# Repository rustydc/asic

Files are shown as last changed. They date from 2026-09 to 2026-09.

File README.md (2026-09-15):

# ASIC LLM research prototype

This repository contains the software-model starting point for a fixed-weight
LLM inference appliance built around the Qwen3.5 dense hybrid geometry.

* [`ARCHITECTURE.md`](ARCHITECTURE.md) records the current appliance and pipeline
  decisions, including the balanced FULL-retrieval policy for every global layer.
* [`fixed_llm_poc.py`](fixed_llm_poc.py) is the correctness-oriented PyTorch
  reference model. Its parameter names match the Hugging Face `Qwen3_5` text
  model so released checkpoints load with a prefix rename. It is not an
  optimized long-context training kernel.
* [`fabric/`](fabric/) defines the fixed-weight fabric tile: a via-programmed
  coefficient ROM feeding 64 MAC columns. It holds the bit-exact reference
  model, the coefficient compiler and via-pattern export, the model-to-tile
  mapping with area and latency estimates, synthesizable RTL verified
  against the model with Icarus Verilog, a yosys flow that measures the
  column datapath on open liberty files (sky130, IHP SG13G2, NanGate 45,
  ASAP7), an OpenSTA driver for pre-layout timing, and an OpenROAD
  place-and-route driver with its sky130 and ASAP7 results.
* [`clash/`](clash/) contains a synthesizable four-stage ASIC-shard seed with a
  deliberately small fixed-coefficient datapath for early RTL and P&R work.
* [`sim/`](sim/) contains the cycle-stepped 32-stage appliance simulator for
  scheduling, phased global execution, backpressure, link, memory-bandwidth,
  and retrieval-geometry sweep experiments, with an energy model that turns
  the measured energy per MAC into board power at the simulated throughput.
* [`training/`](training/) contains the Qwen3.5 checkpoint importer, the
  retrieval candidates, and a layer-wise activation-distillation harness.
* [`hw/`](hw/) contains the block-level board description of the host-attached
  1U (eight layer ASICs, two head-mode ASICs, sixteen LPDDR5X devices, one
  FPGA on a PCIe cable, a BMC, redundant CRPS supplies), its consistency
  checks including a throughput-driven power budget, the rendered block
  diagram, a derivation of the ASIC package and ball map from the power
  model and the interface list, and a generator that turns the description
  into a KiCad 7 project with the board outline and chassis keep-outs,
  placement, stackup, all nets, and the activation ring routed.

## Reference geometries

| Preset | Source model | Hidden | Layers | Body params | Per-ASIC shard |
| --- | --- | ---: | ---: | ---: | ---: |
| `qwen3_5_9b` (default) | Qwen3.5-9B-Base | 4096 | 8 × (3 R + 1 G) | 6.9B | 866M |
| `qwen3_5_4b` | Qwen3.5-4B-Base | 2560 | 8 × (3 R + 1 G) | 3.6B | 447M |

Both presets share the same recurrent heads (32 value × 16 key, 128-dim),
attention heads (16 query × 4 KV, 256-dim), and therefore the same per-context
state formats. Only the fabric width differs, so the 4B is a narrow build of the
same design. Select a preset with `ASICLMConfig.from_preset(name)`; every
variant in `training/variants.json` names one.

## Run

Run the tiny model smoke test and the geometry report in an environment with
PyTorch installed:

```bash
python fixed_llm_poc.py
python -m unittest discover -s training/tests -t .
python -m unittest discover -s sim/tests -t .
python -m unittest discover -s fabric/tests -t .   # RTL tests need iverilog
python -m unittest discover -s hw/tests -t .
```

Import a released checkpoint (needs the `safetensors` package):

```bash
python -m training.qwen35_import --checkpoint /models/Qwen3.5-9B-Base \
    --output checkpoints/asic_init.pt
```

Simulate both geometries:

```bash
python -m sim.run --config sim/config/baseline.json     # 9B
python -m sim.run --config sim/config/qwen35_4b.json    # 4B
python -m sim.run --config sim/config/qwen35_9b_7nm_hbm.json   # 9B, 7 nm-class die, HBM
python -m sim.run --config sim/config/qwen35_9b_3nm_hbm.json   # 9B, 3 nm-class die, HBM
```

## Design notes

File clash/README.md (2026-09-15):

# Clash RTL seed

This directory contains a synthesizable **structural seed**, not the complete 8B
model implementation. It makes the first hardware boundary concrete:

* a tagged activation packet containing no persistent context state;
* four registered, independently operating stages in `R/R/R/G` order;
* literal fixed coefficients that synthesize as constants/connectivity rather
  than an addressed model-weight memory;
* saturating accumulator-to-activation requantization;
* a top entity suitable for Verilog or VHDL generation.

The demo activation width is 16 elements. Expanding it directly to 4096 and
copying the placeholder matrix is not the intended implementation: literal
coefficients do not scale past a demo. The fabric tile that replaces the stage
shell is specified in `fabric/` with synthesizable SystemVerilog in
`fabric/rtl/` and a bit-exact Python model. The next step is to instantiate
that tile array behind these stage boundaries.

## Generate RTL

With GHC, Cabal, and Clash 1.8 installed:

```bash
cd clash
cabal update
cabal build all
cabal test
cabal exec clash -- --verilog src/FixedLLM.hs -main-is FixedLLM.topEntity
```

Generated HDL appears below `verilog/FixedLLM.topEntity/`. The exact location
may include Clash version-specific naming.

## Deliberate omissions

The current global stage is the same registered fixed-projection shell as the
recurrent stages. It does not yet implement recurrent state RAM, local-window
storage, compressed block construction, top-K FULL retrieval, dynamic Q/K/V
attention, backpressure, or the external-memory interface. Those blocks should
be introduced behind the stable `WorkItem` and stage boundaries, with every
global stage retaining the same FULL-retrieval service contract.

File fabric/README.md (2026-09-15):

# Fixed-weight fabric tile

The fabric is the part of the die that holds the model. This directory defines
its unit, the **tile**: a via-programmed coefficient ROM feeding a row of
multiply-accumulate columns. The reference model, the coefficient compiler,
the synthesizable RTL, and the model-to-fabric mapping all live here, and the
RTL is checked bit-exact against the model with Icarus Verilog.

```bash
python -m fabric.tile                        # tile budget for the 9B geometry
python -m fabric.tile --geometry qwen3_5_4b  # and the 4B
python -m unittest discover -s fabric/tests -t .   # model, mapping, and RTL tests
```

## Why a ROM and not pure wiring

A coefficient that is literally a wire between an input line and an
accumulator can never be time-multiplexed, because a static wire cannot select
a different multiple on a different cycle. Pure wiring therefore means one
adder leaf per coefficient, all 866 million of them used once per token. That
is not buildable. The only way a mask-programmed coefficient can share
arithmetic is for the mask to encode a *bit* that a wordline reads out, which
is a ROM.

So the tile is a mask ROM with a very wide read port and the arithmetic sitting
against its bitlines. The architecture doc's "no addressed weight store" is
kept in the sense that matters: the coefficient never leaves the tile, the
read is a few tens of micrometres of bitline, and there is no weight bus,
cache, or DRAM traffic. What is given up is the idea that the weights are
wiring. They are a via pattern in a ROM array, which is denser anyway.

## Tile microarchitecture

```text
                 activations x[r], x[r+1]   (P = 2 rows per cycle, int8)
                        |
          +-------------v--------------+
          | shared multiples per bank  |   0, x, 2x, 3x, 4x, 5x, 6x, 7x
          | (shifts + three adders)    |   11-bit signed
          +----+----+----+---- ... ----+
               |    |    |               one 8-way bus per bank
   ROM row r   v    v    v
   +----+   +--------------------------------------------------+
   |via |-->| column c: select multiple by |w[r][c]|, add/sub  |--> acc[c]  (24-bit)
   |ROM |   | column c+1 ...                                   |
   |    |   +--------------------------------------------------+
   4096 rows x 64 columns x 4 bits = 1 Mbit, 2 banks (even / odd rows)
```

| Parameter | Value | Note |
| --- | ---: | --- |
| Rows (input dims per tile) | 4096 (9B), 2560 (4B) | equals the hidden width; one pass covers a full input vector |
| Columns (outputs per tile) | 64 | |
| Coefficient format | symmetric int4, −7..7 | never −8, so the magnitude selects one of 8 multiples |
| Activation format | int8 | |
| Rows per cycle | 2 | two ROM banks read in parallel; the main area-versus-latency knob |
| Accumulator | 24-bit | worst case 4096 × 127 × 7 fits with margin |
| Requantization | `sat8((acc × mult + 2^(shift−1)) >> shift)` | per-column 16-bit multiplier and 5-bit shift from SRAM, not from the fabric |
| Pass length | rows / rows-per-cycle = 2048 cycles | |

A pass starts by loading the accumulators with chained partial sums (zero for a
fresh pass), consumes two activations per cycle in row order, and after 2048
cycles the shared requantizer walks the columns and publishes the resolved
accumulators and the requantized int8 outputs together. Matrices
wider than 64 outputs use more tiles side by side. Matrices deeper than the
tile, such as the 12288-wide FFN down-projection, use three tiles over
disjoint row ranges in parallel and a partial-sum reduction after them, so
every pass takes the same 2048 cycles.

The per-column requantization constants are the only per-model numbers that
are not in the via pattern. They live in SRAM loaded at boot over the
management SPI, about 80 KB per die.

## Personalization

Every coefficient bit is the presence or absence of one via in the ROM array.
Ten chips, ten via masks, one base mask set. The base wafers can be processed
up to the via layer and banked, then personalized. `Tile.via_count` and
`via_coordinates` produce the pattern the GDS writer places; the row and bit
addressing is fixed here, the bit-cell geometry comes from the foundry ROM
compiler.

Verification per variant is: DRC on the via layer, `decompile` of the via maps
against the quantized weights, and `tile_forward` against `reference_matmul`
on random vectors. No timing closure per variant, because the ROM read and
the column datapath do not depend on which vias are present.

## Mapping the models

The mapping counts tiles per matrix for one `R,R,R,G` shard and for a head
die holding half the vocabulary. All numbers use the placeholder density model
below.

| | 9B layer die | 9B head die | 4B layer die | 4B head die |
| --- | ---: | ---: | ---: | ---: |
| Tiles | 3306 | 1940 | 2858 | 1940 |
| Coefficients | 866M | 509M | 447M | 318M |
| Utilization | 99.9% | 100% | 97.7% | 100% |
| Area at 2 rows/cycle | 242 mm² | 142 mm² | 176 mm² | 119 mm² |
| Latency per layer, 800 MHz | 10.2 µs | 2.6 µs (die) | 6.4 µs | 1.6 µs (die) |
| Fabric energy per token | 62 µJ | 37 µJ | 32 µJ | 19 µJ |

The head slice fits inside a layer die's tile count in both geometries, which
is what makes the head-mode personalization possible. At 50K tokens/s the
fabric energy is about 3 W per 9B layer die before clocks, memory, and I/O.

The rows-per-cycle knob trades column area for latency. ROM area is fixed by
the coefficient count; the MAC columns scale with rows per cycle.

| Rows/cycle | Clock | 9B layer die area | ROM / MAC | Latency per layer | Pass |
| ---: | ---: | ---: | ---: | ---: | ---: |
| 1 | 800 MHz | 218 mm² | 104 / 106 mm² | 20.5 µs | 5.1 µs |
| 2 | 800 MHz | 242 mm² | 104 / 130 mm² | 10.2 µs | 2.6 µs |
| 4 | 800 MHz | 291 mm² | 104 / 179 mm² | 5.1 µs | 1.3 µs |
| 2 | 500 MHz | 242 mm² | 104 / 130 mm² | 16.4 µs | 4.1 µs |

Two rows per cycle is the baseline. The simulator's stage times are derived
from it: 102 ticks (10.2 µs) per 9B layer, 26 ticks per head die.

Because a layer is four sequential passes, a layer stage could accept a new
token every pass (2.6 µs) while a token takes four passes to get through. The
simulator currently treats a layer as one stage with initiation interval equal
to latency, so it understates fabric throughput by up to 4×. It does not
matter yet because the global stage's memory traffic is the bottleneck at
about 66 µs.

## Density model

`DensityModel` holds the numbers behind the tables. The MAC-column entries
are calibrated from open-tooling synthesis (next section); the rest are
placeholders the MPW tile is meant to replace.

| Entry | Value | Source |
| --- | ---: | --- |
| ROM area | 0.03 µm² per bit | placeholder: via-ROM compiler cell at the target node |
| MAC column | 115 µm² per bank | 380 NAND2 equivalents from 64-column sky130 synthesis, at a 0.30 µm² 28 nm NAND2 |
| Accumulator, requantizer share, registers | 385 µm² per column | 1280 NAND2 equivalents, same source |
| Tile overhead | 2500 µm² | placeholder: multiples generator, ROM periphery, control |
| Clock | 800 MHz | placeholder: ROM read plus column add in one cycle |
| ROM read | 3 fJ per bit | placeholder |
| MAC | 60 fJ per coefficient | placeholder |

At these numbers a 28 nm-class 9B layer die is 242 mm², about 43 percent
ROM and 54 percent MAC columns. The timing-clean column (next sections)
costs about 45 percent more than the first ripple-carry version; that is the
price of a pipeline with no carry chain per cycle. At a 16 nm-class node expect roughly
half. If the ROM cell comes in denser than 0.03 µm² per bit, the MAC columns
dominate and one row per cycle becomes the better trade.

## Open tooling and open PDKs

Yes, the column datapath synthesizes with open tooling today, and the numbers
above already come from it. `fabric/synth.py` runs yosys (native or the
`yowasp-yosys` PyPI build) on `fabric_columns` against any liberty file:

```bash
pip install yowasp-yosys
curl -LO https://raw.githubusercontent.com/The-OpenROAD-Project/OpenROAD-flow-scripts/master/flow/platforms/sky130hd/lib/sky130_fd_sc_hd__tt_025C_1v80.lib
python -m fabric.synth --liberty sky130_fd_sc_hd__tt_025C_1v80.lib --rows 256 --cols 16 --rows-per-cycle 2
FABRIC_LIBERTY=$PWD/sky130_fd_sc_hd__tt_025C_1v80.lib python -m unittest fabric.tests.test_synth
```

Measured first on the original ripple-carry column (16 columns, 256 rows,
two rows per cycle) on two manufacturable 130 nm libraries and two predictive
advanced-node kits:

| Library | Kind | NAND2 | Cells | Per column | NAND2-eq per column |
| --- | --- | ---: | ---: | ---: | ---: |
| SkyWater sky130 HD (130 nm) | manufacturable | 3.75 µm² | 12,087 | 5221 µm² | 1392 |
| IHP SG13G2 (130 nm) | manufacturable | 7.26 µm² | 12,027 | 9349 µm² | 1288 |
| NanGate 45 (FreePDK45) | predictive | 0.80 µm² | 12,999 | 1043 µm² | 1307 |
| ASAP7 (7 nm FinFET) | predictive | 0.058 µm² | 11,974 | 74 µm² | 1271 |

Four libraries spanning 130 nm to 7 nm agree within ten percent once
normalized to their own NAND2, so NAND2 equivalents are the number to carry.
The first synthesis run also caught a design error: a per-column requantizer
multiplier that tripled the column area, now a single unit shared across the
64 columns.

The timing work below reshaped the column (carry-save accumulate,
signed-digit taps, a deeper shared requantizer). A full 64-column tile on
sky130 now costs 1663, 2050 and 2808 NAND2 equivalents per column at 1, 2 and
4 rows per cycle, which is the 1280 + 380 per bank the density model uses.

ASAP7 ships its cells in several liberty files; merge them first:

```bash
python -m fabric.synth --merge asap7_tt.lib --liberty SIMPLE.lib --liberty INVBUF.lib \
    --liberty AO.lib --liberty OA.lib --liberty SEQ.lib
python -m fabric.synth --liberty asap7_tt.lib --rows 256 --cols 16 --rows-per-cycle 2
```

On the predictive kits: FreePDK15 (NC State, 15 nm FinFET) is the same kind
of thing as ASAP7 and NanGate 45, an academic model of a node with no fab
behind it. Its standard cells are the NanGate 15 nm library distributed by
Silvaco behind a registration, so it is not fetchable in a script the way the
OpenROAD platforms are, and ASAP7 already gives the below-28 nm bracket. Any
of them is fine for relative area, useless for a tapeout.

What open PDKs can and cannot do for this project:

* **Relative column cost: yes, done above.** Predictive kits (NanGate 45,
  ASAP7, FreePDK15) bracket the target node from both sides.
* **The MPW tile: yes.** A 1024 × 64 test tile on sky130 or IHP SG13G2 is
  about a square millimetre of columns plus a hand-drawn via-ROM array, and
  both processes run open shuttles. That measures the column datapath, the
  ROM cell, and the personalization flow end to end, at 130 nm.
* **Timing: yes, pre-layout and placed-and-routed.** OpenSTA builds from
  source in a few minutes and times the yosys netlist against the same
  liberty files; OpenROAD then places, buffers, clocks and routes it on
  the sky130 and ASAP7 platform files. See the next two sections.
* **The production die: no.** At 130 nm the ROM cell is 30 to 50 times larger
  than at 28 nm, so the 9B layer die would be several thousand square
  millimetres. The production node needs a foundry PDK under NDA.
* **OpenRPDK28 (RIOS Lab): not yet.** It is an academic 28 nm template
  under construction with device models and rule decks but, as far as its
  repository shows, no standard-cell library or liberty timing, and it is
  not tied to a foundry, so nothing built on it can be fabricated. It may
  become useful for checking a via-ROM cell against 28 nm-class design rules
  once it matures.

A further density lever, not in the baseline, is current-mode readout: drive
wordlines with the activation as a pulse width, sum bitline currents, and
digitize once per column. That removes the column datapath entirely and is
the only path well below 0.15 µm² per coefficient, at the cost of analog
precision risk. It is a second-generation experiment.

## Timing on 130 nm and 7 nm

`fabric/sta.py` runs OpenSTA on a netlist written by `fabric/synth.py`
(`--target-ps` for timing-driven mapping, `--netlist` to keep it), with a
clock constraint and ten percent input and output delays:

```bash
python -m fabric.synth --liberty sky130.lib --rows 256 --cols 16 --rows-per-cycle 2 \
    --target-ps 2500 --netlist net_sky130.v
python -m fabric.sta --sta /path/to/OpenSTA/build/sta --liberty sky130.lib \
    --netlist net_sky130.v --period-ps 2500 --report
```

Results for the column datapath at two rows per cycle, typical corner:

| Library | Critical path | Of which unbuffered fanout | Logic-depth limit |
| --- | ---: | ---: | ---: |
| sky130 HD, 130 nm | 4.25 ns | 1.4 ns (80-load flop) | 235 MHz, ~310 MHz buffered |
| ASAP7, 7 nm predictive | 0.73 ns | 0.14 ns (52-load flop) | 1.37 GHz, ~1.7 GHz buffered |

What these numbers are: post-synthesis, pre-layout, no wire load, no clock
tree, ideal clock, one corner, and no cell sizing or buffering beyond what
ABC does inside one combinational block. Flop-driven nets are not buffered,
so the first line of every critical path is a fat unbuffered fanout that
place-and-route would fix; the "buffered" column subtracts it and charges a
buffer tree instead. ASAP7 maps to its smallest cells throughout, so it is
pessimistic in the other direction. Budget 20 to 40 percent on top for wires.

Read across the nodes: 130 nm at roughly 300 MHz and predictive 7 nm at
roughly 1.7 GHz bracket a 28 nm-class part somewhere around 0.6 to 1.2 GHz
for this logic depth. The 800 MHz placeholder is inside that range, not
proven by it. The MPW tile and a foundry library settle it.

Getting here changed the design, and every change was driven by a reported
critical path:

1. **Requantizer multiplier per column** (3000 cells per column): made one
   shared unit that walks the columns after the pass.
2. **41-bit ripple-carry adds** in the requantizer at 6 to 9 ns on sky130:
   yosys emits ripple adders and ABC cannot restructure carry chains, so the
   multiply became a carry-save tree with the rounding constant folded in and
   the final add runs in three 14-bit chunks over three stages.
3. **Column select fanout** (`q_col` on 600 accumulator mux bits): replaced by
   a one-hot walking select, 69 loads per bit regardless of column count.
4. **Control strobes** merged back into one 600-load net by synthesis even
   with `keep`: the per-column copies are now their own module with
   `keep_hierarchy`.
5. **Pre-adders for 3x, 5x, 7x** on the activation path: every coefficient
   magnitude is now a signed pair of power-of-two taps, so stage A has no
   arithmetic at all.
6. **24-bit accumulate and the term sum**, ripple again: both are carry-save.
   The accumulator is a (sum, carry) pair with a constant-depth 3:2 reduction
   per cycle; the carries resolve once per pass in the requantizer walk, in
   two 12-bit chunks. The term sum reduces the four taps and the negation
   count to a carry-save pair at accumulator width, so no width change and
   no wrap can occur.
7. **Datapath resets** removed; `start` loads the accumulators, everything
   else free-runs, and only control keeps an asynchronous reset.

The column pipeline is now A (inputs), B (term reduction), C (accumulate);
the requantizer is select, two resolve stages, multiply, three add stages,
and shift/saturate, nine cycles of latency after the 64-cycle walk. All of
it stays bit-exact against the Python model, which never changed.

## Place and route

`fabric/pnr.py` drives OpenROAD through floorplan, timing-driven global
placement, resize and buffering, clock-tree synthesis, hold repair, global
routing, and post-route timing on wire parasitics extracted from the global
route. It uses the platform files from OpenROAD-flow-scripts (LEF, RC
tables, track scripts) and the same netlists OpenSTA timed above:

```bash
micromamba create -p eda -c litex-hub -c conda-forge openroad   # or build from source
git clone --depth 1 https://github.com/The-OpenROAD-Project/OpenROAD-flow-scripts orfs
python -m fabric.pnr --openroad eda/bin/openroad --platform sky130hd \
    --platforms-dir orfs/flow/platforms --netlist net_sky130.v \
    --period-ps 3000 --utilization 35 --work pnr_sky130
python -m fabric.pnr --openroad eda/bin/openroad --platform asap7 \
    --platforms-dir orfs/flow/platforms --netlist net_asap7.v \
    --liberty asap7_tt.lib --period-ps 700 --utilization 45 --work pnr_asap7
```

Results for the same 256-row, 16-column, two-rows-per-cycle slice, after
global routing, typical corner (`fabric/results/pnr_*.json` holds the parsed
numbers and the final critical path):

| | sky130 HD, 130 nm | ASAP7, 7 nm predictive |
| --- | ---: | ---: |
| Target period | 3.00 ns | 700 ps |
| Worst slack | −1.15 ns | −2.7 ps |
| Achievable clock | **241 MHz** | **1.42 GHz** |
| Pre-layout estimate | 235 MHz (310 buffered) | 1.37 GHz (1.7 buffered) |
| Clock insertion / skew | 1.9 ns, 8 levels / 470 ps | 280 ps, 4 levels / 73 ps |
| Hold buffers | 3051 | 1584 |
| Design area | 215,071 µm² (47 %) | 2,623 µm² (45 %) |
| Placed area before repair | 159,971 µm² | 2,646 µm² |
| Instances | 28,034 | 23,621 |
| Wirelength | 1.48 m | 131 mm |
| Routing overflow (global) | 297 edges, ≤ 6 per edge | 0 |

The pre-layout numbers hold up. On ASAP7 the routed design is a little
faster than the unbuffered estimate: the resizer fixes the fanout the STA
run flagged, and wires, the clock tree and 73 ps of skew cost less than
that fix gains. On sky130 the routed flop-to-flop path is 4.2 ns, the same
as the unbuffered pre-layout path, so none of the expected buffering gain
arrived (see below); the 2345-sink clock tree built from `clkbuf_4` alone
is eight levels and 1.9 ns deep, but its 470 ps of skew happens to favour
the worst path. The 28 nm-class bracket stays where the previous section
put it, roughly 0.6 to 1.2 GHz, with the 800 MHz placeholder inside it.

What limits each node now:

* **ASAP7:** the critical path is twenty-seven XOR and NAND levels in the
  requantizer, the ripple form ABC leaves a 14-bit chunk add in, plus the
  skew between two clock branches. Both are design choices: narrower
  chunks or a conditional-sum adder should be worth 100 to 150 ps, and a
  two-level clock mesh removes most of the skew. Neither is worth doing
  before the target library is known.
* **sky130:** the critical path runs through the walking select and the
  requantizer input mux, and one `o41ai_4` cell on it drives a 64 fF net
  at a 0.9 ns slew that the resizer gave up on (`RSZ-0062`, three times).
  That one cell is 0.85 ns of a 4.2 ns path. It is a buffering failure
  rather than a logic-depth limit; a hand-placed buffer tree on the select
  would recover most of the missing 300 MHz. It only matters for the MPW
  tile.

Area moves in the expected direction. Sky130 grows 34 percent in place and
route, almost all of it the 3051 hold buffers that propagated-clock skew
forces on a design whose datapath registers have no logic between them in
the walk, plus the clock tree. ASAP7 does not grow at all because the
resizer downsizes 10,390 cells that yosys had mapped larger than needed,
which pays for its 1584 hold buffers. Per column slice the routed area is
3585 NAND2 equivalents on sky130 and 2827 on ASAP7, against 2050 for a
column of the 64-wide tile pre-layout; the 16-column slice amortizes the
shared requantizer over four times fewer columns, which accounts for most
of the difference. The density model still carries the pre-layout
64-column figure. The sky130 run says place and route can add a third on
top of it, mostly hold buffers a better clock tree would reduce, and the
ASAP7 run says it can add nothing; the die-size table should be read with
that spread in mind until the target library settles it.

What this run is not: detailed routing (`--detailed-route` runs it, at
several times the wall time), a signoff extraction, multiple corners, or a
power grid. The global router reports no overflow on ASAP7 and a few
hundred lightly overfull edges on sky130 at 35 percent target utilization,
so both would detail-route; the sky130 slice is pin-limited, with 1390
ports on a 0.68 mm square, which is an artifact of routing a slice rather
than the whole tile.

Two things the flow had to work around in the litex-hub OpenROAD build of
February 2024: `report_wire_length` crashes on a typo in its error path,
so wirelength comes from the router's own log line, and `> file`
redirection on several report commands writes empty files, so every report
goes to the log and `parse_results` reads that.

## Detailed routing, power grid and IR drop

`--detailed-route` extends the flow: well taps and the platform's power
grid go in at floorplan (`pdngen` with the OpenROAD-flow-scripts strategy,
M1/M2 rails with M5/M6 stripes on ASAP7, met1 rails with met4/met5 stripes
on sky130), and after global routing it runs TritonRoute, fill cells,
OpenRCX extraction, timing on the extracted parasitics, `report_power`,
and static IR-drop analysis of both supply nets.

```bash
python -m fabric.pnr --openroad eda/bin/openroad --platform asap7 \
    --platforms-dir orfs/flow/platforms --netlist net_asap7.v \
    --liberty asap7_tt.lib --period-ps 700 --utilization 25 \
    --detailed-route --work pnr_asap7_drt --json
```

ASAP7, same 256-row 16-column slice, after detailed routing and
extraction (`fabric/results/pnr_asap7_signoff.json`):

| | ASAP7, 7 nm predictive |
| --- | ---: |
| Detailed-route DRC violations | 0 (8 iterations); 0 antenna violations |
| Timing on extracted parasitics | 700 ps met exactly, **1.43 GHz** |
| Same path on global-route estimates | −8 ps |
| Clock skew | 75 ps |
| Cells (before 38,086 fillers) | 26,433 |
| Design area | 3,311 µm² at 31 % of a 107 µm die |
| Wirelength | 157 mm |
| Power (default 10 % activity, 1.43 GHz) | 17.9 mW: 61 % internal, 39 % switching |
| Static IR drop, VDD | 364 mV worst at the core edge, 12 mV average |

The timing story does not change from global routing to signoff: the
extracted parasitics come in slightly under the global-route estimate, and
the slice closes at exactly the 700 ps it was asked for. The pre-layout
bracket for 28 nm stands.

The power grid is the new information. The slice draws 1.7 W/mm² at the
default activity, which is high, and the platform's default grid was not
made for that: 18 nm M1/M2 rails fed from M5/M6 stripes every 5.4 µm lose
100 mV or more on half of the cells, and 364 mV at the right core edge,
where the last stripe sits 3 µm from the boundary. That result is with a
supply point on every top-layer node (this build turns `-dx 20 -dy 20`
into 4.2 million sources), so it is the distribution loss alone; a real
bump grid adds to it. For the tile this says two things: stripe pitch and
rail width are first-order design parameters at this power density, and
the density model's 800 MHz at 28 nm will need a grid sized from the
measured current, not the platform default. It does not change the area
model.

Getting a pin-dense slice through this build's TritonRoute took some
care, and each item is a flag or an experiment in `fabric/pnr.py`:

* constants must be tie cells (`hilomap` on the mapped netlist, with
  `opt_clean -purge` and `setundef -zero` first) or the router refuses
  the supply-typed nets they become;
* buffers inserted by post-route timing repair must be legalized and the
  design re-routed before detailed routing;
* on ASAP7 the router could not reach a handful of M4/M5 I/O pins on the
  left and bottom edges whatever the stub length or spacing (experiments
  A and B); with 1 µm stubs on the top and right edges only (experiment
  C) it routes cleanly;
* `pin_access` before global routing puts guides on M9 on ASAP7 and is
  therefore off there;
* the routing derating follows the flow scripts (0.25 on ASAP7, 0.2 on
  sky130): at 0.5 the slice overflowed by a few edges and the guides of
  those nets were unusable;
* on sky130 the router rejected every net on a pin whose li1 and met1
  shapes are separate LEF `PORT`s (xor2 B, dfrtp RESET_B, mux, fa) when
  the ports straddle a gcell boundary; the driver merges those ports in
  a copy of the cell LEF, and the resizer is told not to use the probe
  cells it had been picking as hold buffers.

sky130 signoff: pending (see the results file when it lands).

## RTL

`rtl/fabric_tile.sv` is the synthesizable tile with the ROM as a constant
array loaded from a hex image. It is parameterized in rows, columns,
coefficient and activation width, rows per cycle, and accumulator and
requantizer widths. In silicon the ROM array and the multiple-select crossbar
become a hard macro; the RTL is the functional stand-in and the synthesis
baseline for the column datapath.

`rtl/tb_fabric_tile.sv` reads vectors written by `fabric.tile.emit_vectors`,
streams the activations with occasional bubbles, and compares the raw
accumulators and requantized outputs against the model. The tests run three
configurations through Icarus Verilog: 64×8 with chained partial sums, 256×64
at four rows per cycle, and 4096×16 at full depth.

## What is next

1. Detailed routing and a multi-corner pass of the OpenROAD flow above, a
   buffer tree on the walking select for sky130, and then the same flow on
   the target library.
2. A via-ROM compiler cell from the foundry, or a hand-drawn cell for the MPW,
   to replace the ROM area and read energy placeholders.
3. The GDS writer: `via_coordinates` into the ROM macro's bit-cell grid.
4. Pass-level pipelining in the simulator so a layer stage's initiation
   interval is one pass rather than four.
5. A multi-token variant of the column datapath for chunked prefill, which
   amortizes the ROM read across a chunk of tokens from one context.

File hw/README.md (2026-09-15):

# Appliance board (revision A0)

Block-level schematic capture for the first appliance board. `board.yaml` is
the source of truth; `python -m hw.board` checks it and regenerates
`board.svg` (block diagram) and `board.md` (bill of materials, power, pin
budget, ring order). Everything here is a budget to validate, not a vendor-
confirmed number, until the ASIC pinout and power are characterized.

```bash
python -m hw.board            # check, then write board.svg and board.md
python -m unittest discover -s hw/tests -t .
```

## Form factor: a host-attached 1U

The board is a single 420 × 360 mm board in a 1U rack chassis, attached to
a host over a PCIe cable. The first draft was a full-length PCIe card; the
energy model below moved it out of the slot. At 3 pJ per MAC the board
draws 0.5 to 1.6 kW of input across the throughput range, which is a rack
power supply and a row of fans, not a 600 W auxiliary connector on a
passively cooled card. The 1U also has the room the 50K tokens/s package
needs (29 mm bodies, 62 mm column pitch, 76 mm row-change hop) and a
management controller. The chassis layout:

* rear panel: the SlimSAS 8i host connector next to the FPGA, the BMC's
  RJ45, the optional SFP+ cage, the status LEDs;
* rear right: the PSU bay with two CRPS modules in a 1+1 redundant pair;
* the ring runs front to back down the middle of the board, FPGA and head
  ASICs at the rear, the row change under the front fans;
* front: six 40 mm fans blowing front to back over the two ASIC rows.

The KiCad generator keeps the card as a second form factor
(`form_factor_key: pcie_card`), which still builds at the 14.5K rating with
the 23 mm package; the tests check both.

## Population

| Part | Qty | Role |
| --- | ---: | --- |
| Layer ASIC | 8 | four decoder layers each, personalized coefficient masks, layer-mode strap |
| Head ASIC | 2 | same die, head-mode strap, each holds half of the 248K-row LM head; no memory |
| LPDDR5X 16 Gb x32 | 16 | two per layer ASIC: 4 GB and 77 GB/s raw per ASIC at 9600 MT/s |
| Controller FPGA | 1 | PCIe Gen4 x8 endpoint over the host cable, ring source and sink, sampling, scheduling |
| DDR4 x16 | 4 | 4 GB on the FPGA for the embedding table and per-context metadata |
| Clock generator | 1 | reference clock to all eleven devices |
| BMC | 1 | AST2600-class: PSU PMBus, fan control, thermal, FPGA console, its own Ethernet |
| Host cable connector | 1 | SlimSAS 8i (SFF-8654): PCIe Gen4 x8 plus sideband to a host adapter card |
| CRPS receptacle | 2 | 12 V from each supply module, 1+1 redundant |
| Fan header | 6 | 4-pin PWM, one per front fan |
| SFP+ cage | 1 (optional) | standalone 10GbE operation, rear panel |

## Topology

One unidirectional activation ring:

```text
FPGA -> A0 -> A1 -> A2 -> A3 -> A4 -> A5 -> A6 -> A7 -> H0 -> H1 -> FPGA
```

Each hop is the 32-bit source-synchronous DDR link from the architecture doc
(36 signals, 2 GB/s raw, under 80 mm). Head chips forward the incoming hidden
vector unchanged and append their top-k logits and partial softmax sum, so no
broadcast path is needed. The FPGA merges the two lists and samples.

Layer ASICs sit in two rows of four so the ring snakes out along row A and
back along row B, ending next to the FPGA. Both head chips sit at the rear
end of row B, the FPGA directly beside H1. Each layer ASIC has one LPDDR5X
device on either side.

Management is a SPI bus from the FPGA with one chip select per ASIC, a JTAG
chain through all eleven devices, and a fanned-out reference clock. Each ASIC
has a two-pin mode strap (layer or head). The BMC owns the chassis: PSU
PMBus, fan PWM and tach, the core regulators' PMBus, the FPGA's UART
console, and its own Ethernet port.

## Power

ASIC power is no longer a placeholder: it is throughput times energy per
token, from the `power_model` block in `board.yaml`. The one measured input
is the energy of a fixed-weight multiply-accumulate in the column datapath,
0.39 pJ on ASAP7 at the tool's default activity
(`fabric/results/pnr_asap7_signoff.json`), which derates to about 1 pJ for
real activity and projects to 2 to 4 pJ on a 28 nm-class node; the model
carries 3 pJ. Each layer ASIC does 866M MACs per token (9B geometry), each
head ASIC 508M, and the layer ASICs also move about 4.2 MB per token of
index and KV traffic at roughly 40 pJ per byte. The other parts keep fixed
budgets (1 W per LPDDR5X, 25 W FPGA, 5 W BMC, 12 W per fan).

At the simulator's 14.5K tokens/s ceiling that is 43 W per layer ASIC and
517 W of load, 608 W of 12 V input at 85 percent regulator efficiency.
`board.md` tabulates the same at 5K, 25K and 50K tokens/s: the board runs
from about 330 W to 1.66 kW of input across the throughput range, and a
layer ASIC's core rail goes from 21 A to 177 A at 0.8 V. The supply is
therefore two 2000 W CRPS modules in a 1+1 redundant pair, one of which
carries the whole load, and each ASIC needs a multiphase core regulator.
A 7 nm-class die at about 1 pJ per MAC would put the whole range back under
600 W and make the card viable again; the process choice is the biggest
lever on the power supply and the enclosure.

The power tree is a 12 V intermediate bus from the CRPS modules into
point-of-load regulators. Each ASIC gets its own core buck with PMBus
telemetry so per-chip current is observable during bring-up. The LPDDR5X
rails, 1.8 V I/O, FPGA rails, DDR4 rails, and 3.3 V housekeeping are shared.

## Host interface: PCIe over a cable, and why not Ethernet or PoE

**PoE is out.** The highest PoE class (802.3bt Type 4) delivers 71 W to the
device. This board needs hundreds of watts at any useful throughput. Even a
4B-geometry build at the lowest rate in the table sits well above the PoE
ceiling once the FPGA and memory are counted.

**Ethernet as the data path is viable but not the first build.** The token
traffic is tiny. At 50K tokens/s with a few hundred bytes per token, both
directions together are under 20 MB/s, and a 128K prefill moves 512 KB of
token ids. Even 1GbE would carry it. The reasons to still start with PCIe:

* the FPGA's hard PCIe block is the cheapest working host link, with no
  network stack to write in fabric;
* PCIe round trips are a few microseconds, below the 250 to 500 µs token
  latency target, while a network hop adds tens of microseconds and jitter.

The 1U is host-attached: a SlimSAS 8i cable from the rear panel to a
retimer or host adapter card in the server next to it, the same arrangement
as an external PCIe expansion chassis. PCIe Gen4 x4 is enough bandwidth; the
board wires x8 because the FPGA's hard block is x8 and the cable carries it.

The SFP+ cage on the rear panel keeps the standalone-appliance option open.
The FPGA transceivers are there anyway, so a later firmware can serve a UDP
or gRPC-style token protocol over 10GbE with no board change, and the
chassis already has its own supply and management.

## ASIC package and ball map

`python -m hw.pinout` derives the ASIC package and its ball map from the
board description and writes `hw/pinout/asic_ballmap.csv`, `asic_ballmap.json`
and `report.md`. The pinout is co-designed with the die floorplan and the
substrate, and the substrate is the packaging house's work; what we owe them
is the ball count the power model demands, the package that carries it, and
a ball map with the constraints a substrate and a PCB can both route. The
rules live in the `package_selection` block of `board.yaml`:

* the core rail needs one ball per 0.5 A at the rated throughput, and ground
  matches it plus one return per four signal balls;
* signals sit in the outer three rows, where a through via escapes them;
* each interface owns a package edge, which is also the die-edge assignment
  for the I/O ring: link in west, link out east as two columns of 18 rows,
  both LPDDR5X channels on the north rows in byte lanes with a ground after
  each lane, management, JTAG, reference clock and mode strap on the south
  row, ground and the core rail in a checkerboard elsewhere;
* the smallest candidate package that satisfies all of that is selected.

The package is rated at the 50K tokens/s target, where the core rail draws
177 A: 354 core balls, 354 ground balls, 54 signal returns, 216 signals and
34 rail balls, 1012 in all. That selects a 1225-ball 35 × 35 array at
0.8 mm in a 29 mm body. The 784-ball 23 mm package of the card draft is
enough at the 14.5K design point (520 balls) and is what the card form
factor still uses; 400 balls never are. The rating is a decision: it fixes
the package before the die exists, and the 1U was retargeted partly so the
larger package fits.

The KiCad generator builds every ASIC footprint from this map, so the ball
pitch, the escape geometry, the via-in-pad counts and the ring's lane pitch
follow it. `hw/pinout/report.md` lists the candidates with the reason each
was rejected or chosen, the ball counts by use, and the memory signals that
sit deeper than the outer three rows and need a build-up escape.

## KiCad project

`python -m hw.kicad_gen` turns `board.yaml` into a KiCad 7 project under
`hw/kicad/` (`appliance.kicad_pro`, `.kicad_pcb`, `.kicad_sch` with four
sub-sheets, `report.md`, `floorplan.svg`). It regenerates from the YAML, so
the description stays the source of truth. The files are written directly in
KiCad's S-expression formats; the generator itself needs only PyYAML, and
KiCad is used to open and check the result. The tests run KiCad's own
design-rule check when its `pcbnew` Python module is installed (`apt install
kicad` on Ubuntu 24.04) and pass with no violation other than the unrouted
nets.

Floorplan

The ring is laid out in its own frame (u along the rows, v across them) and
the form factor maps that frame onto the physical board: on the 1U the
frame is rotated so the rows run front to back, with the FPGA and the head
ASICs at the rear beside the host connector. What the project contains:

* the 420 × 360 mm 1U board with its keep-outs (PSU bay, rear I/O strip,
  fan row), the SlimSAS host connector, the BMC and its RJ45, the two CRPS
  receptacles, six fan headers and the SFP+ cage, all placed physically and
  checked against the keep-outs;
* all 44 parts of `board.yaml` on generated footprints, plus one core
  regulator block per ASIC and seven shared-rail regulator blocks. Row A
  runs rear to front and row B is rotated 180 degrees so the ring snakes
  back; the memories sit outside the rows, the regulators between them,
  and the two head ASICs at the rear of row B with the FPGA beside H1 so
  the closing hop stays short;
* the ASIC ball map derived by `hw/pinout.py` (see above), shared by all ten
  ASICs, with the head ASICs' memory balls unconnected. The FPGA's link pins
  are assigned by the ribbon router; its other pins are placeholders;
* every net at the signal level (1,754 nets), so schematic and board agree:
  ring links, sixteen LPDDR5X channels, the DDR4 x64, PCIe to the host
  connector, management SPI, JTAG chain, reference clocks, mode straps,
  the BMC's fan, PMBus and console nets, and the rails;
* a twelve-layer stackup with four ground planes, a 12 V and I/O rail layer
  and a core-rail layer, via-in-pad on every ground and rail ball a zone can
  reach, and ground, 12 V, memory-PHY and core-rail zones;
* the activation ring fully routed: each straight hop is one 36-lane ribbon
  on In2.Cu, and each bent hop is split by escape depth into two 18-lane
  ribbons on In2.Cu and In5.Cu that taper from the ball pitch to 0.25 mm in
  their body so the corners stay cheap. Every hop is within the 80 mm link
  limit; the longest are the row change at 76 mm and the closing hop into
  the FPGA at 74 mm.

What it does not contain, on purpose: routed memory, PCIe or management nets
(length matching and signal integrity are interactive work), decoupling,
regulator internals, thermal vias, mounting holes, chassis mechanicals, or
a real ASIC ball map. `report.md` carries the link lengths, the escape
density (the 130 memory signals per ASIC north edge need a build-up layer
pair to escape), and the core-rail current density: at 50K tokens/s a layer
ASIC draws about 177 A, which is over 80 A/mm² on a single 2 oz plane across
the package width, so the real board needs the regulator against the package
with several plane layers between them.

Floorplan findings from routing the ring, on the card and again on the 1U:

* The head ASICs must sit beside the FPGA. The card's first draft put them
  at the bracket end and the closing hop came to 85 mm.
* With the 29 mm package the closing hop into the FPGA's south edge was
  95 mm. The FPGA now sits directly beside H1 and takes the ring on its
  west edge, which brings the hop to 74 mm; the PCIe pins moved to the
  FPGA's south edge, towards the host connector.
* The row-change hop meets the limit only with the rows one regulator band
  apart, the lanes compressed to 0.25 mm and the ribbon split over two
  layers; at the via pitch on one layer it was 105 mm on the card. With
  29 mm bodies it is 76 mm, so the package rating has used up the margin.
  If the single-ended 1.8 V link keeps its 80 mm budget these constraints
  are real; the LVDS fallback in `board.yaml` would relax them.
* The 1U is mostly empty: the ring strip is 111 mm wide on a 420 mm board.
  That is room for the regulators to spread out, for a second board
  revision to carry two rings, or for a shorter chassis.

## Open items before schematic entry in an EDA tool

1. ASIC package and ball map: the derived map in `hw/pinout/` goes to the
   packaging house with the bump map once the die floorplan exists; the
   substrate design and the final map come back from them.
2. Measured energy per MAC on the target process, which sets the core
   regulator sizing and the supply rating; the 3 pJ in `board.yaml` is a
   projection from the ASAP7 signoff run.
3. Link I/O standard: 1.8 V single-ended at 500 Mb/s per pin needs a signal
   integrity check at 80 mm; fall back to eight LVDS pairs at 2 Gb/s if it
   fails.
4. LPDDR5X versus GDDR6. The simulator wants 75 to 100 GB/s per ASIC with
   int4 KV; two LPDDR5X-9600 x32 devices give 77 GB/s raw. GDDR6 doubles that
   at higher PHY effort and power.
5. FPGA part selection against the pin budget in `board.md`: two links, DDR4
   x64, PCIe x8, SPI with ten chip selects, JTAG, optional SFP+.
6. Host side: the retimer or adapter card and the cable length the Gen4
   link tolerates; the fallback is a Gen3 cable or a redriver at the
   rear panel.
7. Thermal: 1.4 kW of load in 1U at 50K tokens/s is at the limit of
   front-to-back air over 29 mm packages; the 25K row (0.8 kW) is the
   comfortable air-cooled point.

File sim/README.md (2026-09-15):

# Appliance architecture simulator

This is a deterministic, cycle-stepped transaction-level simulator for the
eight-ASIC appliance. It moves tagged work items rather than real tensors and
models the resources that determine system throughput:

* 32 finite-queue layer stages in `R/R/R/G` order, followed by one stage per
  head-mode ASIC (`num_head_asics`, `head_cycles`) that forwards the hidden
  vector plus `head_result_bytes` of top-k partial result;
* one unresolved token per autoregressive context;
* round-robin FPGA injection and configurable sampling delay;
* serialized links at ASIC boundaries;
* identical FULL retrieval at all global stages;
* context-length-dependent index/KV reads and append writes;
* configurable sustainable LPDDR efficiency and per-ASIC bandwidth;
* overlapped index, top-K, KV, attention, and output global-stage phases;
* downstream backpressure, utilization, latency, and FIFO watermarks.

The global memory model is intentionally coarse. It converts index and KV bytes
to service cycles using sustained bandwidth; it does not yet model LPDDR banks,
row locality, refresh, or outstanding transaction limits. The simulator should
eventually consume timing measured from RTL and emit memory traces for a detailed
DRAM simulator.

## Run

From the repository root:

```bash
python -m unittest discover -s sim/tests -t .
python -m sim.run --config sim/config/baseline.json      # Qwen3.5-9B geometry
python -m sim.run --config sim/config/qwen35_4b.json     # Qwen3.5-4B geometry
python -m sim.run --config sim/config/qwen35_9b_7nm_hbm.json   # 7 nm-class die, HBM per ASIC
python -m sim.run --config sim/config/qwen35_9b_3nm_hbm.json   # 3 nm-class die, HBM per ASIC
python -m sim.run --config sim/config/baseline.json --trace trace.json
python -m sim.sweep --kv-element-bytes 1,0.5 --top-blocks 32,16 --output retrieval-sweep.csv
```

The trace command writes a Chrome/Perfetto-compatible trace. Open it in Perfetto
to inspect stage occupancy by context and token.

Warm-up tokens are simulated but excluded from reported throughput and latency,
which reduces pipeline fill bias. `global_max_inflight` controls how many
contexts can occupy different global-engine phases at once. Index and selected
KV transfers still share the configured memory interval.

The sweep reports bytes/token, operation latency, initiation interval, and the
global-stage throughput ceiling across index dimension, index precision,
compression, KV element size, top-K, and bandwidth combinations. It is
analytical and therefore much faster than running every point through the full
pipeline.

## Configurations

Both configurations use the Qwen3.5 head geometry: `kv_heads=4` KV heads of
`head_dim=256`, so a stored position costs 2 KB at int8. Both add two
head-mode ASICs after the last layer chip. Fabric stage times come from the
tile model in `fabric/` at two rows per cycle and 800 MHz: four passes of
2048 cycles per 9B layer (`recurrent_cycles` 102 ticks) and one pass per head
die (26 ticks); the 4B tile is 2560 deep, so 64 and 16 ticks. A layer is
modeled as one stage whose initiation interval equals its latency; pass-level
pipelining would cut the interval to one pass but the global stage is the
bottleneck regardless. The 4B configuration
keeps every memory parameter identical and scales fabric cycles by the
446M/865M per-shard parameter ratio. `activation_bytes` assumes int8 activations
of the hidden width (4096 or 2560).

Two further configurations ask where the ceiling goes once the memory
wall is removed. `qwen35_9b_7nm_hbm.json` puts the 9B geometry on a
7 nm-class die at the ASAP7 signoff clock of 1.43 GHz (57 ticks per layer)
with one HBM3E stack per layer ASIC (1 TB/s, int4 KV at 16:1, 128 resident
contexts), an 8 GB/s ring link, 1 pJ per MAC and 200 W of static power for
the stacks and FPGA. `qwen35_9b_3nm_hbm.json` extrapolates to 2 GHz
(41 ticks), 1.5 TB/s, 256 contexts, a 16 GB/s link and 0.5 pJ per MAC. The
global index-scan compute placeholder scales with the clock and with the
four times fewer compressed positions. Neither models pass-level
pipelining, so a layer stage still admits one token per layer latency.

Each result also carries an energy model: `mac_energy_pj` times the MACs
per token of every layer and head ASIC (`layer_macs_per_token`,
`head_macs_per_token`) gives compute energy per token, the accumulated
global-stage memory traffic times `memory_energy_pj_per_byte` gives memory
energy, and `static_power_w` is the fixed floor (FPGA, DRAM idle, ASIC
leakage and I/O). The result reports energy per token, compute, memory and
board power at the measured throughput, and the dynamic power of one layer
ASIC. The 3 pJ per MAC in both configurations is the ASAP7 signoff figure
(0.39 pJ at default activity, `fabric/results/pnr_asap7_signoff.json`)
derated for real activity and projected to a 28 nm-class node; a 7 nm-class
die would be about 1 pJ. The sweep adds the same two columns at each
point's global-stage ceiling.

Fabric cycle scales, global phase timing, sustained memory efficiency, and link
throughput are hypotheses to be replaced with RTL and memory-system
measurements. The baseline uses a 10 MHz architecture tick (100 ns), while
preserving the intended microsecond service times and bytes/second. This is a
simulation time quantum rather than the proposed RTL clock and makes long
pipeline sweeps fast.

## Current finding

With int8 KV at 4:1 compression, 32 retrieved blocks, and 64 GB/s sustained
bandwidth, both geometries saturate the global stage at about 14.5K tokens/s
with a 128K context, below the 25K to 50K target. The recurrent stages sit at
15 percent (9B) or 10 percent (4B) utilization, the head stages under 5
percent, and the ring links under 4 percent. The global memory interval is
half index scan and half selected-KV transfer. The sweep shows int4 KV plus
8:1 compression recovers 30K tokens/s at 75 GB/s and 40K at 100 GB/s; 16:1
compression with int4 KV reaches the 50K ceiling at 100 GB/s.

Power scales with that throughput, not with the fabric clock. At 3 pJ per
MAC the 9B token costs 24 mJ of compute and about 1.3 mJ of memory traffic,
so the 14.5K tokens/s baseline is 346 W of compute, 20 W of memory and
436 W for the board, 38 W of it in each layer ASIC; the sweep points that
reach 40K tokens/s cost about 1.06 kW. The energy per MAC, which the
process sets, is the lever: at 1 pJ the same points are 150 W and 400 W.

With HBM the wall moves to the fabric. The 7 nm-class configuration
reaches 169K tokens/s at 230 µs mean latency with every layer stage at
99 percent, the global memory phases short, the links at 12 percent and
the head stages at 25 percent; the 3 nm-class one reaches 236K tokens/s
at 165 µs. The limiter in both is the un-pipelined pass rate, one token
per 8192 fabric cycles per stage, so pass-level pipelining (item 4 in the
fabric README) is worth up to four times more, and the 128 or 256
contexts are not yet binding. Power is the other wall: 1.6 kW for the
board at 7 nm (147 W per layer ASIC, 7.9 mJ per token) and 1.2 kW at 3 nm
(102 W per layer ASIC, 4.0 mJ per token), so both are liquid-cooled boxes
rather than cards.

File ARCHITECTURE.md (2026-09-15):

# Fixed-Weight LLM Inference Appliance

**Status:** Concept / pre-architecture  
**Target:** Dense Qwen3.5-9B-geometry inference appliance with 128K context,
with the Qwen3.5-4B geometry as a narrow first build  
**Primary objective:** Test whether immutable model weights implemented directly
in silicon can sustain high decode throughput in a simple, multi-chip pipeline.

All performance, capacity, cost, and die-size figures in this document are
targets to validate. They are not characterized-silicon results.

## Architectural thesis

The appliance removes the two dominant sources of conventional inference
traffic:

* model coefficients are physical configuration rather than fetched weights;
* most layers use bounded recurrent state, while the remaining layers retrieve
  a sparse subset of compressed long-context state.

The model and each context's persistent state stay local. Only an activation and
its routing metadata move between stages.

```text
moving:              hidden vector, context ID, position, flags
persistent locally:  recurrent state, compressed global-attention context
fixed at manufacture: model weights
```

## Reference model and package partition

The reference model is the Qwen3.5 dense hybrid geometry, which already has the
`R/R/R/G` layer pattern the appliance needs:

* 24 Gated DeltaNet bounded-state recurrent layers (`R`): 32 value heads and
  16 key heads of 128 dimensions, a 4-tap causal convolution, and an output gate;
* 8 gated-attention global layers (`G`): 16 query heads sharing 4 KV heads of
  256 dimensions with rotary embedding on the first 64 dimensions;
* a dense SwiGLU feed-forward block in every layer.

| Preset | Hidden | FFN width | R layer | G layer | Per-ASIC shard | Body | Embedding + head |
| --- | ---: | ---: | ---: | ---: | ---: | ---: | ---: |
| `qwen3_5_9b` | 4096 | 12288 | 218M | 211M | 866M | 6.93B | 2.03B (untied) |
| `qwen3_5_4b` | 2560 | 9216 | 113M | 108M | 447M | 3.58B | 0.64B (tied) |

The head geometry is identical in both presets, so every per-context state
format, the recurrent update logic, and the retrieval engine are shared. Only
the fabric width changes. Recurrent and global layers are within four percent
of each other in parameters, so the stages are balanced without moving FFN
capacity between them. The software model still permits distinct recurrent and
global FFN widths, but any such change discards the copied feed-forward weights
and must be justified by training results.

The 248K-entry vocabulary makes the LM head 1.0B multiply-accumulates per token
(0.64B for the 4B). At the throughput targets that is beyond an FPGA, and the
head does not fit one layer die's 866M-coefficient fabric. The head is
therefore two additional layer dies in **head mode**: the same base design with
a head personalization, each holding half of the vocabulary rows. The
embedding table lives in FPGA memory.

Head mode needs three features in the base design:

* an input broadcast so all four stage fabrics see the same hidden vector,
  with residual and norm bypassed;
* a top-k plus log-sum-exp reduce on the output, so a head chip emits a few
  hundred bytes instead of 124K logits;
* a two-pin mode strap.

A head chip forwards the incoming work item unchanged and appends its partial
result, so the ring needs no broadcast path. The FPGA merges the two lists and
samples. Head chips have no external memory.

Eight ASICs each implement four consecutive layers, and two more ASICs of the
same design run in head mode. Every layer is an independent physical pipeline
stage.

```text
FPGA -> ASIC 0 -> ASIC 1 -> ... -> ASIC 7 -> HEAD 0 -> HEAD 1 -> FPGA
        L0-L3     L4-L7           L28-L31   vocab     vocab
                                            rows 0-   rows
                                            124159    124160-

inside each layer ASIC:
input -> recurrent -> recurrent -> recurrent -> sparse global -> output
```

All ten parts share arithmetic, control, interfaces, and base physical design.
Only the mask-programmed coefficient connectivity and the mode strap differ.
The board-level capture of this topology is in `hw/`.

## Fixed-weight layer fabric

The fixed fabric evaluates `y = Wx` with no weight bus, cache, or DRAM traffic
in the inference path. Its unit is the **tile** defined in `fabric/`: a
via-programmed ROM of 4096 × 64 int4 coefficients read two rows per cycle,
feeding 64 multiply-accumulate columns. Each activation's coefficient
multiples are formed once per bank; every column selects its multiple through
the ROM word and adds or subtracts it. The coefficient never leaves the tile;
the read is a few tens of micrometres of bitline.

Coefficients are ROM bits, not wiring. A coefficient that is literally a wire
cannot be time-multiplexed, so pure wiring would need one adder per
coefficient. A mask-programmed bit read by a wordline is what lets the
arithmetic be shared, and a via ROM is denser than wiring or SRAM in any case.
Each of the ten chips is therefore the same base mask set plus one via mask.

A 9B layer die maps to 3306 tiles at 99.9 percent utilization, about 240 mm²
at a 28 nm-class node with the ROM cell still a placeholder and the MAC
columns calibrated by open-tooling synthesis on four libraries from 130 nm
to a predictive 7 nm. Static timing of the column after OpenROAD placement,
clock-tree synthesis and global routing gives 241 MHz on sky130 and
1.42 GHz on ASAP7, which brackets the 28 nm clock at roughly 0.6 to
1.2 GHz; the 800 MHz assumption sits inside that range. A layer is four
sequential passes of 2048 cycles, 10.2 µs at 800 MHz. The head die is
1940 tiles.

The gating physical-design experiment is a tile on the candidate PDK, and it
must measure:

* via-ROM bit-cell area and read energy, which set the ROM half of the die;
* column datapath area at one, two, and four rows per cycle;
* the ROM-read-plus-add cycle time;
* power, IR drop, and thermal density at full pass rate;
* that the via layer is the only mask that changes between variants.

If four approximately 215M-parameter layers do not fit economically, the
fallbacks are the 4B geometry (four approximately 110M-parameter layers per
device) or sixteen two-layer devices.

## Long-context state

Each global layer combines:

1. exact causal attention over a recent window;
2. compressed long-term key/value blocks;
3. a learned, low-dimensional block index;
4. top-K block retrieval followed by dynamic attention over the selected data.

Block selection is intentional: selected context reads become contiguous memory
bursts rather than arbitrary token gathers. Representative training variables
are a 256-1024 token exact window, approximately 4:1 long-term compression, a
128-dimensional index, and 256-1024 retrieved compressed positions. These values
remain software parameters until model quality and hardware traces justify
freezing them.

### Balanced global-layer policy

Every global layer performs the same **FULL** retrieval algorithm against its
own local context. The design does **not** alternate FULL and REUSE layers and
does not send candidate lists between ASICs.

This choice deliberately trades redundant index work for a regular pipeline:

* all eight global stages have the same latency and bandwidth envelope;
* the inter-chip work item remains small and deterministic;
* no global layer depends on retrieval decisions made from another layer's
  representation;
* scheduling does not need separate FULL/REINDEX/REUSE stage classes.

Hierarchical or chunked index scanning remains an allowed implementation detail
inside every global stage. It must preserve the same observable FULL-retrieval
semantics and a common stage budget.

A stored position carries four 256-dimensional KV heads, 2 KB at int8 or 1 KB
at int4. At 4:1 compression a 128K-token context therefore needs about 64 MB
per global layer at int8 plus the 128-dimensional index, and about 32 MB at
int4. Since each ASIC owns one global layer, 32 resident contexts consume
roughly 1-2 GB before allocator and metadata overhead. A 2-4 GB local memory
device still fits, but the margin is smaller than the earlier single-KV-head
estimate, and the simulator shows bandwidth, not capacity, is the binding
constraint (see "Performance targets").

## Context ownership and work item

The initial system supports at least 32 resident contexts. Every ASIC owns the
state for its local layers, indexed by the context identifier.

```c
struct WorkItem {
    uint8_t context_id;   // five significant bits in revision A
    uint8_t flags;
    uint32_t position;
    activation_t hidden[4096];   // 2560 in the 4B build
};
```

Candidate IDs are intentionally absent. A simple PoC may statically reserve
equal memory regions for every context.

## Pipeline scheduling

Autoregression prevents unresolved tokens from one context from occupying
multiple stages, because token `N+1` cannot enter layer 0 until token `N` has
completed layer 31 and sampling. Independent contexts can occupy different
stages simultaneously. Thirty-two runnable contexts nominally fill the pipeline;
additional contexts provide slack for memory and control variability.

The slowest stage sets aggregate throughput. Because all global stages use the
same policy, their target service time must be balanced explicitly against one
another and should be made as deterministic as practical.

The architecture simulator represents a global operation as index scan, top-K,
selected-KV transfer, attention, and output phases. Different contexts may
occupy different phase engines concurrently, while index and KV traffic contend
for the same local memory interface. Reported steady-state metrics exclude a
configurable warm-up interval. Memory bandwidth is derated by an explicit
efficiency factor and includes context append writes.

## Interfaces and memory

PCIe terminates at the controller FPGA. Adjacent ASICs use a narrow,
source-synchronous, ready/valid packet link with framing and CRC. A candidate
revision-A link is 32 data bits at 250 MHz DDR (2 GB/s raw). At 50K work items/s,
a BF16 4096-element hidden vector consumes about 400 MB/s before framing, leaving
substantial raw-link margin.

Each layer ASIC provisionally receives two LPDDR5X x32 devices (4 GB, about
77 GB/s raw at 9600 MT/s) for its one global layer. The bandwidth target is at
least 50 GB/s per ASIC, preferably 75-100 GB/s; GDDR6 is the fallback if the
sweep demands the top of that range. Head ASICs have no external memory.
Actual compressed-state formats and measured access traces must close both
capacity and bandwidth before architecture freeze.

The FPGA owns PCIe Gen4 (x8 wired, x4 sufficient) and 4 GB of DDR4 for the
embedding table and context metadata. Power-over-Ethernet cannot supply a
board that draws hundreds of watts, and PCIe gives lower host latency than a
network hop, so the first board is a host-attached 1U: one board in a rack
chassis with redundant CRPS supplies and a BMC, reached over a SlimSAS PCIe
cable from the host, with an optional SFP+ cage for a later standalone mode
(see `hw/README.md`). The energy model moved it out of a PCIe slot: at 3 pJ
per MAC the board draws 0.5 to 1.6 kW across the throughput range.

The FPGA owns the host protocol, scheduling, sampling, context allocation,
bring-up, telemetry, error recovery, and performance counters. Speculative
generation is deferred until ordinary autoregressive decode is characterized.

## Performance targets

| Condition | Architectural target |
| --- | ---: |
| 128K, one context | 2K-4K token/s |
| 128K, pipeline full | 25K-50K token/s |
| Short context, one context | 4K-8K token/s |
| Short context, pipeline full | 40K+ token/s |

These targets imply roughly 250-500 microseconds of end-to-end single-context
latency and a 20-40 microsecond worst-stage service time. A cycle-accurate model
must derive both figures from fixed-fabric, memory, link, and queue timing rather
than assume them.

The transaction-level simulator with the Qwen3.5 head geometry, int8 KV, 4:1
compression, 32 retrieved blocks, and 64 GB/s sustained bandwidth saturates the
global stage at about 14.5K tokens/s for both presets at 128K context, with the
recurrent stages under 10 percent busy. Half of the global memory interval is
the index scan and half is the selected-KV transfer. Reaching the 25K-50K
target needs some combination of int4 KV storage, 8:1 or 16:1 compression,
fewer retrieved blocks, and 75-100 GB/s sustained bandwidth. Those are now the
first parameters the software model must qualify.

Power follows throughput. The column datapath measures 0.39 pJ per
multiply-accumulate on ASAP7 at default activity after detailed routing and
extraction (`fabric/results/pnr_asap7_signoff.json`); derated for real
activity and projected to a 28 nm-class node that is about 3 pJ, so a 9B
token costs roughly 24 mJ of compute across the ten ASICs. The simulator and
the board model both carry that figure: the 14.5K tokens/s baseline is about
440 W of board load, 25K tokens/s about 700 W, and 50K tokens/s 1.3 kW, with a
layer ASIC's core rail between 50 A and 180 A. A 7 nm-class process at about
1 pJ per MAC divides all of those by three. The choice of node is therefore
as much a power-supply decision as an area one, and the on-die grid must be
sized from measured current: the ASAP7 slice lost half its supply on the
platform's default grid at 1.7 W/mm².

## Development gates

1. **Software model:** import the Qwen3.5 weights, recover acceptable quality
   at 128K with the retrieval replacement in the eight global layers, and
   freeze retrieval, KV precision, compression, and fabric quantization formats.
2. **Architecture simulator:** validate the 32-stage multi-context schedule,
   local state management, memory traces, backpressure, and packet protocol.
3. **Fixed-weight tile macro:** demonstrate credible ROM density, column
   datapath timing, power, and via-mask personalization on the target process,
   driven by the coefficient compiler in `fabric/`.
4. **Small silicon:** validate the coefficient/connectivity fabric against the
   physical estimates on an MPW test chip. The head-mode personalization is
   the natural vehicle: one matrix, no state, no memory interface.
5. **Full appliance:** tape out the eight layer variants and the two head
   variants only after the preceding gates pass.

The largest open risks are fixed-connectivity routing density, global-stage
memory bandwidth at the Qwen3.5 KV width, model-quality loss from replacing
full attention with windowed retrieval in the eight global layers,
architecture-specific weight quantization (especially below 4 bits on the 4B),
placement of the 1B-parameter LM head, external-memory PHY effort, power
delivery at hundreds of watts per board and over 100 A per die, and yield
across eight large coefficient variants.

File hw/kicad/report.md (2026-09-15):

# KiCad floorplan report

Generated by `python -m hw.kicad_gen` from `hw/board.yaml`. Do not edit.

1U rack chassis, single board, host-attached: 420 x 360 mm, 12 copper layers, 61 footprints, 1754 nets, 1188 track segments, 13740 vias, 19 zones. Keep-outs: PSU bay (two CRPS) (273,0)-(420,190); rear I/O (0,0)-(273,12); front fans (0,352)-(420,360).

## Stackup

| Layer | Role |
| --- | --- |
| F.Cu | signal |
| In1.Cu | GND |
| In2.Cu | link signals |
| In3.Cu | 12 V and I/O rails |
| In4.Cu | GND |
| In5.Cu | link signals (second half of bent hops), memory signals |
| In6.Cu | memory signals |
| In7.Cu | GND |
| In8.Cu | core rails |
| In9.Cu | signal |
| In10.Cu | GND |
| B.Cu | signal |

## Activation ring

36 lanes per hop, 0.1 mm tracks. A straight hop is one ribbon on In2.Cu at 0.4 mm lane pitch (outer-column and dogbone vias interleaved). A bent hop is split by escape depth into two 18-lane ribbons on In2.Cu and In5.Cu, each tapering over 7.1 mm from 0.8 mm at the vias to 0.25 mm in its body so the corners cost the outer lane little; the FPGA end rescales to its own 1.0 mm pitch. Limit 80 mm per `board.yaml`.

| Hop | Shortest lane (mm) | Longest lane (mm) | Within limit |
| --- | ---: | ---: | --- |
| U_FPGA -> U_A0 | 44.9 | 54.7 | yes |
| U_A0 -> U_A1 | 29.4 | 35.6 | yes |
| U_A1 -> U_A2 | 29.4 | 35.6 | yes |
| U_A2 -> U_A3 | 29.4 | 35.6 | yes |
| U_A3 -> U_A4 | 52.8 | 76.5 | yes |
| U_A4 -> U_A5 | 29.4 | 35.6 | yes |
| U_A5 -> U_A6 | 29.4 | 35.6 | yes |
| U_A6 -> U_A7 | 29.4 | 35.6 | yes |
| U_A7 -> U_H0 | 3.4 | 9.6 | yes |
| U_H0 -> U_H1 | 3.4 | 9.6 | yes |
| U_H1 -> U_FPGA | 50.0 | 73.8 | yes |

## ASIC package and escape density

FCBGA1225_35x35_P0.8: 35x35 balls at 0.8 mm, 29 mm body, selected by `hw/pinout.py` for 177 A of core current at 50000 tokens/s (1012 balls needed; see `hw/pinout/report.md`). Per edge: 36 link signals on two columns of 18 rows (2.5 signals per mm of edge); 130 LPDDR signals on the north 4 rows, 4.5 per mm of edge, of which 28 sit deeper than the outer 3 rows and need microvias or a build-up layer pair to escape. The memory nets are not routed here.

## Core rail current

One 2 oz (70 um) plane across the package width, at 50K tokens/s from the board power model:

| ASIC | Current (A) | Section per plane (mm2) | A/mm2 on one plane | Planes for 30 A/mm2 |
| --- | ---: | ---: | ---: | ---: |
| U_A0 | 177 | 2.03 | 87 | 3 |
| U_A1 | 177 | 2.03 | 87 | 3 |
| U_A2 | 177 | 2.03 | 87 | 3 |
| U_A3 | 177 | 2.03 | 87 | 3 |
| U_A4 | 177 | 2.03 | 87 | 3 |
| U_A5 | 177 | 2.03 | 87 | 3 |
| U_A6 | 177 | 2.03 | 87 | 3 |
| U_A7 | 177 | 2.03 | 87 | 3 |

The core rail therefore needs the regulator directly beside the package with several plane layers or thick copper in between; the single In8.Cu island here is a placeholder.

## Not done here

* LPDDR5X, DDR4 and PCIe are present as nets and unrouted (length matching and impedance work).
* No decoupling capacitors, no VRM internals, no thermal vias, no mounting holes.
* The ASIC ball map is the rule-derived one from hw/pinout.py; the final one comes from the package design.
* The FPGA link pins are assigned by the ribbon router; every other FPGA pin is a placeholder.
* The BMC, PSU and fan connectors are placeholder blocks with their nets; no chassis mechanicals.

## Notes

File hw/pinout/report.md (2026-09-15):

# ASIC package and ball map

Derived by `python -m hw.pinout` from `hw/board.yaml`. Do not edit.

## Requirements

Rated at 50000 tokens/s the core rail draws 177 A (3.0 pJ per MAC, 0.8 V), one ball per 0.5 A.

| Need | Balls |
| --- | ---: |
| Signals (72 link, 130 memory, 14 management) | 216 |
| Signal ground returns (1 per 4) | 54 |
| Core rail | 354 |
| Ground for the core | 354 |
| VDD_IO_1V8 | 8 |
| VDD_PLL_0V9 | 2 |
| VDD2H_1V05 | 12 |
| VDDQ_0V3 | 12 |
| **Total** | **1012** |

## Candidates

| Package | Balls | Outer rows | Body | Verdict |
| --- | ---: | ---: | ---: | --- |
| FCBGA400_20x20_P1.0 | 400 | 204 | 23 mm | 400 balls, 1012 needed |
| FCBGA784_28x28_P0.8 | 784 | 300 | 23 mm | 784 balls, 1012 needed |
| FCBGA1225_35x35_P0.8 | 1225 | 384 | 29 mm | **selected** |
| FCBGA961_31x31_P1.0 | 961 | 336 | 33 mm | not needed |

## Ball map

FCBGA1225_35x35_P0.8: 35 x 35 at 0.8 mm, 29 mm body.

| Use | Balls | Where |
| --- | ---: | --- |
| link_in | 36 | W edge, columns 1-2, rows 9-26 |
| link_out | 36 | E edge, same rows |
| lpddr_ch0, lpddr_ch1 | 130 | N rows, byte lanes with a ground after each |
| mgmt, jtag, refclk, strap | 14 | S row |
| VDD_CORE | 464 | interior checkerboard |
| GND | 511 | interior checkerboard and lane returns |
| VDD_IO_1V8 | 8 | interior |
| VDD_PLL_0V9 | 2 | interior |
| VDD2H_1V05 | 12 | interior |
| VDDQ_0V3 | 12 | interior |

Signal balls deeper than the outer 3 rows: 28 (these need a microvia or build-up escape on the PCB).

## What the packaging house gets

* this map as `asic_ballmap.csv`, with the edge each interface must face;
* the die-edge assignment it implies: link ports on the west and east die edges, both LPDDR5X PHYs on the north edge, management on the south;
* the core current (177 A at the rating, 177 A at 50K tokens/s) for the bump map and the substrate power planes.

The substrate design, the bump map and the final ball map come back from them; the loop usually runs two or three times and this file is regenerated from the agreed rules each round.

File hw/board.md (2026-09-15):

# asic-llm-appliance-a0 board summary

Generated by `python -m hw.board` from `hw/board.yaml`. Do not edit.

## Bill of materials (major parts)

| Class | Qty | Description | Power each at 14500 tok/s (W) |
| --- | ---: | --- | ---: |
| layer_asic | 8 | fixed-weight 4-layer shard die (personalized coefficient masks) | 43.1 |
| head_asic | 2 | same die as layer_asic, head-mode personalization (LM head half) | 24.1 |
| lpddr5x | 16 | LPDDR5X 16 Gb x32, 9600 MT/s (38.4 GB/s raw per device) | 1.0 |
| fpga | 1 | controller FPGA with hard PCIe Gen4 block and DDR4 controller (AU25P/KU5P class) | 25.0 |
| ddr4 | 4 | DDR4 x16 for the embedding table and context metadata (4 x16 = x64, 4 GB) | 0.8 |
| clock_gen | 1 | low-jitter clock generator, 12+ outputs (Si5345 class) | 0.5 |
| sfp_cage | 1 | SFP+ cage on the rear panel for standalone 10GbE operation (optional fit) | 1.5 |
| host_cable | 1 | SlimSAS 8i (SFF-8654) receptacle, PCIe Gen4 x8 plus sideband, to a host adapter card | 0.0 |
| bmc | 1 | baseboard management controller (AST2600 class) with its own Ethernet, fans, PSU PMBus, FPGA UART | 5.0 |
| rj45 | 1 | BMC management Ethernet, rear panel | 0.5 |
| psu_input | 2 | CRPS 12 V output blade receptacle (one per module) with PMBus and enable | 0.0 |
| fan_header | 6 | 4-pin PWM fan header, one per 40 mm front fan | 12.0 |

## Power

At the design point of 14500 tokens/s and 3.0 pJ per MAC: load 517 W, input 608 W at 85% regulator efficiency, available 2000 W.

| Tokens/s | Layer ASIC (W) | Core current at 0.80 V (A) | Load (W) | Input (W) |
| ---: | ---: | ---: | ---: | ---: |
| 5000 | 17 | 21 | 277 | 326 |
| 14500 | 43 | 54 | 517 | 608 |
| 25000 | 72 | 90 | 781 | 919 |
| 50000 | 141 | 177 | 1410 | 1659 |

## Activation ring

U_FPGA -> U_A0 -> U_A1 -> U_A2 -> U_A3 -> U_A4 -> U_A5 -> U_A6 -> U_A7 -> U_H0 -> U_H1 -> U_FPGA

## Signal pin budget per instance (excluding power and ground)

| Class | Signal pins |
| --- | ---: |
| layer_asic | 216 |
| head_asic | 86 |
| lpddr5x | 65 |
| fpga | 262 |
| ddr4 | 58 |

## Link

32-bit source-synchronous DDR parallel link, 250 MHz clock (2 GB/s raw), ready/valid, CRC in packet; 36 signals per hop, 11 hops, max 80 mm.

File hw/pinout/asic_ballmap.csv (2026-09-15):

ball | row | col | x_mm | y_mm | kind | interface | signal | escape_edge | escape_depth
A1 | 0 | 0 | -13.600 | 13.600 | signal | lpddr_ch0 | DQ0
A2 | 0 | 1 | -12.800 | 13.600 | signal | lpddr_ch0 | DQ1
A3 | 0 | 2 | -12.000 | 13.600 | signal | lpddr_ch0 | DQ2
A4 | 0 | 3 | -11.200 | 13.600 | signal | lpddr_ch0 | DQ3
A5 | 0 | 4 | -10.400 | 13.600 | signal | lpddr_ch0 | DQ4
A6 | 0 | 5 | -9.600 | 13.600 | signal | lpddr_ch0 | DQ5
A7 | 0 | 6 | -8.800 | 13.600 | signal | lpddr_ch0 | DQ6
A8 | 0 | 7 | -8.000 | 13.600 | signal | lpddr_ch0 | DQ7
A9 | 0 | 8 | -7.200 | 13.600 | signal | lpddr_ch0 | DQS0_P
A10 | 0 | 9 | -6.400 | 13.600 | signal | lpddr_ch0 | DQS0_N
A11 | 0 | 10 | -5.600 | 13.600 | signal | lpddr_ch0 | DMI0
A12 | 0 | 11 | -4.800 | 13.600 | ground | GND
A13 | 0 | 12 | -4.000 | 13.600 | signal | lpddr_ch0 | DQ8
A14 | 0 | 13 | -3.200 | 13.600 | signal | lpddr_ch0 | DQ9
A15 | 0 | 14 | -2.400 | 13.600 | signal | lpddr_ch0 | DQ10
A16 | 0 | 15 | -1.600 | 13.600 | signal | lpddr_ch0 | DQ11
A17 | 0 | 16 | -0.800 | 13.600 | signal | lpddr_ch0 | DQ12
A18 | 0 | 17 | 0.000 | 13.600 | signal | lpddr_ch0 | DQ13
A19 | 0 | 18 | 0.800 | 13.600 | signal | lpddr_ch0 | DQ14
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

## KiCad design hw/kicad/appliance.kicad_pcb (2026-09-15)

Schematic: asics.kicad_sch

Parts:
U_A0, U_A1, U_A2, U_A3, U_A4, U_A5, U_A6, U_A7: layer_asic; FCBGA1225_35x35_P0.8
U_H0, U_H1: head_asic; FCBGA1225_35x35_P0.8

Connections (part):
A0_CH0_CA0: U_A0.B14; also elsewhere on the board
A0_CH0_CA1: U_A0.B15; also elsewhere on the board
A0_CH0_CA2: U_A0.B16; also elsewhere on the board
A0_CH0_CA3: U_A0.B17; also elsewhere on the board
A0_CH0_CA4: U_A0.B18; also elsewhere on the board
A0_CH0_CA5: U_A0.B19; also elsewhere on the board
A0_CH0_CA6: U_A0.B20; also elsewhere on the board
A0_CH0_CA7: U_A0.B21; also elsewhere on the board
A0_CH0_CA8: U_A0.B22; also elsewhere on the board
A0_CH0_CA9: U_A0.B23; also elsewhere on the board
A0_CH0_CA10: U_A0.B24; also elsewhere on the board
A0_CH0_CA11: U_A0.B25; also elsewhere on the board
A0_CH0_CA12: U_A0.B26; also elsewhere on the board
A0_CH0_CA13: U_A0.B27; also elsewhere on the board
A0_CH0_CK0_N: U_A0.B31; also elsewhere on the board
A0_CH0_CK0_P: U_A0.B30; also elsewhere on the board
A0_CH0_CK1_N: U_A0.B33; also elsewhere on the board
A0_CH0_CK1_P: U_A0.B32; also elsewhere on the board
A0_CH0_CS0: U_A0.B28; also elsewhere on the board
A0_CH0_CS1: U_A0.B29; also elsewhere on the board
A0_CH0_DMI0: U_A0.A11; also elsewhere on the board
A0_CH0_DMI1: U_A0.A23; also elsewhere on the board
A0_CH0_DMI2: U_A0.A35; also elsewhere on the board
A0_CH0_DMI3: U_A0.B12; also elsewhere on the board
A0_CH0_DQ0: U_A0.A1; also elsewhere on the board
A0_CH0_DQ1: U_A0.A2; also elsewhere on the board
A0_CH0_DQ2: U_A0.A3; also elsewhere on the board
A0_CH0_DQ3: U_A0.A4; also elsewhere on the board
A0_CH0_DQ4: U_A0.A5; also elsewhere on the board
A0_CH0_DQ5: U_A0.A6; also elsewhere on the board
A0_CH0_DQ6: U_A0.A7; also elsewhere on the board
A0_CH0_DQ7: U_A0.A8; also elsewhere on the board
A0_CH0_DQ8: U_A0.A13; also elsewhere on the board
A0_CH0_DQ9: U_A0.A14; also elsewhere on the board
A0_CH0_DQ10: U_A0.A15; also elsewhere on the board
A0_CH0_DQ11: U_A0.A16; also elsewhere on the board
A0_CH0_DQ12: U_A0.A17; also elsewhere on the board
A0_CH0_DQ13: U_A0.A18; also elsewhere on the board
A0_CH0_DQ14: U_A0.A19; also elsewhere on the board
A0_CH0_DQ15: U_A0.A20; also elsewhere on the board
A0_CH0_DQ16: U_A0.A25; also elsewhere on the board
A0_CH0_DQ17: U_A0.A26; also elsewhere on the board
A0_CH0_DQ18: U_A0.A27; also elsewhere on the board
A0_CH0_DQ19: U_A0.A28; also elsewhere on the board
A0_CH0_DQ20: U_A0.A29; also elsewhere on the board
A0_CH0_DQ21: U_A0.A30; also elsewhere on the board
A0_CH0_DQ22: U_A0.A31; also elsewhere on the board
A0_CH0_DQ23: U_A0.A32; also elsewhere on the board
A0_CH0_DQ24: U_A0.B2; also elsewhere on the board
A0_CH0_DQ25: U_A0.B3; also elsewhere on the board
A0_CH0_DQ26: U_A0.B4; also elsewhere on the board
A0_CH0_DQ27: U_A0.B5; also elsewhere on the board
A0_CH0_DQ28: U_A0.B6; also elsewhere on the board
A0_CH0_DQ29: U_A0.B7; also elsewhere on the board
A0_CH0_DQ30: U_A0.B8; also elsewhere on the board
A0_CH0_DQ31: U_A0.B9; also elsewhere on the board
A0_CH0_DQS0_N: U_A0.A10; also elsewhere on the board
A0_CH0_DQS0_P: U_A0.A9; also elsewhere on the board
A0_CH0_DQS1_N: U_A0.A22; also elsewhere on the board
A0_CH0_DQS1_P: U_A0.A21; also elsewhere on the board
A0_CH0_DQS2_N: U_A0.A34; also elsewhere on the board
A0_CH0_DQS2_P: U_A0.A33; also elsewhere on the board
A0_CH0_DQS3_N: U_A0.B11; also elsewhere on the board
A0_CH0_DQS3_P: U_A0.B10; also elsewhere on the board
A0_CH0_RESET: U_A0.B34; also elsewhere on the board
A0_CH1_CA0: U_A0.D14; also elsewhere on the board
A0_CH1_CA1: U_A0.D15; also elsewhere on the board
A0_CH1_CA2: U_A0.D16; also elsewhere on the board
A0_CH1_CA3: U_A0.D17; also elsewhere on the board
A0_CH1_CA4: U_A0.D18; also elsewhere on the board
A0_CH1_CA5: U_A0.D19; also elsewhere on the board
A0_CH1_CA6: U_A0.D20; also elsewhere on the board
A0_CH1_CA7: U_A0.D21; also elsewhere on the board
A0_CH1_CA8: U_A0.D22; also elsewhere on the board
A0_CH1_CA9: U_A0.D23; also elsewhere on the board
A0_CH1_CA10: U_A0.D24; also elsewhere on the board
A0_CH1_CA11: U_A0.D25; also elsewhere on the board
A0_CH1_CA12: U_A0.D26; also elsewhere on the board
A0_CH1_CA13: U_A0.D27; also elsewhere on the board
A0_CH1_CK0_N: U_A0.D31; also elsewhere on the board
A0_CH1_CK0_P: U_A0.D30; also elsewhere on the board
A0_CH1_CK1_N: U_A0.D33; also elsewhere on the board
A0_CH1_CK1_P: U_A0.D32; also elsewhere on the board
A0_CH1_CS0: U_A0.D28; also elsewhere on the board
A0_CH1_CS1: U_A0.D29; also elsewhere on the board
A0_CH1_DMI0: U_A0.C11; also elsewhere on the board
A0_CH1_DMI1: U_A0.C23; also elsewhere on the board
A0_CH1_DMI2: U_A0.C35; also elsewhere on the board
A0_CH1_DMI3: U_A0.D12; also elsewhere on the board
A0_CH1_DQ0: U_A0.C1; also elsewhere on the board
A0_CH1_DQ1: U_A0.C2; also elsewhere on the board
A0_CH1_DQ2: U_A0.C3; also elsewhere on the board
A0_CH1_DQ3: U_A0.C4; also elsewhere on the board
A0_CH1_DQ4: U_A0.C5; also elsewhere on the board
A0_CH1_DQ5: U_A0.C6; also elsewhere on the board
A0_CH1_DQ6: U_A0.C7; also elsewhere on the board
A0_CH1_DQ7: U_A0.C8; also elsewhere on the board
A0_CH1_DQ8: U_A0.C13; also elsewhere on the board
A0_CH1_DQ9: U_A0.C14; also elsewhere on the board
A0_CH1_DQ10: U_A0.C15; also elsewhere on the board
A0_CH1_DQ11: U_A0.C16; also elsewhere on the board
A0_CH1_DQ12: U_A0.C17; also elsewhere on the board
A0_CH1_DQ13: U_A0.C18; also elsewhere on the board
A0_CH1_DQ14: U_A0.C19; also elsewhere on the board
A0_CH1_DQ15: U_A0.C20; also elsewhere on the board
A0_CH1_DQ16: U_A0.C25; also elsewhere on the board
A0_CH1_DQ17: U_A0.C26; also elsewhere on the board
A0_CH1_DQ18: U_A0.C27; also elsewhere on the board
A0_CH1_DQ19: U_A0.C28; also elsewhere on the board
A0_CH1_DQ20: U_A0.C29; also elsewhere on the board
A0_CH1_DQ21: U_A0.C30; also elsewhere on the board
A0_CH1_DQ22: U_A0.C31; also elsewhere on the board
A0_CH1_DQ23: U_A0.C32; also elsewhere on the board
A0_CH1_DQ24: U_A0.D2; also elsewhere on the board
A0_CH1_DQ25: U_A0.D3; also elsewhere on the board
A0_CH1_DQ26: U_A0.D4; also elsewhere on the board
A0_CH1_DQ27: U_A0.D5; also elsewhere on the board
A0_CH1_DQ28: U_A0.D6; also elsewhere on the board
A0_CH1_DQ29: U_A0.D7; also elsewhere on the board
A0_CH1_DQ30: U_A0.D8; also elsewhere on the board
A0_CH1_DQ31: U_A0.D9; also elsewhere on the board
A0_CH1_DQS0_N: U_A0.C10; also elsewhere on the board
A0_CH1_DQS0_P: U_A0.C9; also elsewhere on the board
A0_CH1_DQS1_N: U_A0.C22; also elsewhere on the board
A0_CH1_DQS1_P: U_A0.C21; also elsewhere on the board
A0_CH1_DQS2_N: U_A0.C34; also elsewhere on the board
A0_CH1_DQS2_P: U_A0.C33; also elsewhere on the board
A0_CH1_DQS3_N: U_A0.D11; also elsewhere on the board
A0_CH1_DQS3_P: U_A0.D10; also elsewhere on the board
A0_CH1_RESET: U_A0.D34; also elsewhere on the board
A1_CH0_CA0: U_A1.B14; also elsewhere on the board
A1_CH0_CA1: U_A1.B15; also elsewhere on the board
A1_CH0_CA2: U_A1.B16; also elsewhere on the board
A1_CH0_CA3: U_A1.B17; also elsewhere on the board
A1_CH0_CA4: U_A1.B18; also elsewhere on the board
A1_CH0_CA5: U_A1.B19; also elsewhere on the board
A1_CH0_CA6: U_A1.B20; also elsewhere on the board
A1_CH0_CA7: U_A1.B21; also elsewhere on the board
A1_CH0_CA8: U_A1.B22; also elsewhere on the board
A1_CH0_CA9: U_A1.B23; also elsewhere on the board
A1_CH0_CA10: U_A1.B24; also elsewhere on the board
A1_CH0_CA11: U_A1.B25; also elsewhere on the board
A1_CH0_CA12: U_A1.B26; also elsewhere on the board
A1_CH0_CA13: U_A1.B27; also elsewhere on the board
A1_CH0_CK0_N: U_A1.B31; also elsewhere on the board
A1_CH0_CK0_P: U_A1.B30; also elsewhere on the board
A1_CH0_CK1_N: U_A1.B33; also elsewhere on the board
A1_CH0_CK1_P: U_A1.B32; also elsewhere on the board
A1_CH0_CS0: U_A1.B28; also elsewhere on the board
A1_CH0_CS1: U_A1.B29; also elsewhere on the board
A1_CH0_DMI0: U_A1.A11; also elsewhere on the board
A1_CH0_DMI1: U_A1.A23; also elsewhere on the board
A1_CH0_DMI2: U_A1.A35; also elsewhere on the board
A1_CH0_DMI3: U_A1.B12; also elsewhere on the board
A1_CH0_DQ0: U_A1.A1; also elsewhere on the board
A1_CH0_DQ1: U_A1.A2; also elsewhere on the board
A1_CH0_DQ2: U_A1.A3; also elsewhere on the board
A1_CH0_DQ3: U_A1.A4; also elsewhere on the board
A1_CH0_DQ4: U_A1.A5; also elsewhere on the board
A1_CH0_DQ5: U_A1.A6; also elsewhere on the board
A1_CH0_DQ6: U_A1.A7; also elsewhere on the board
A1_CH0_DQ7: U_A1.A8; also elsewhere on the board
A1_CH0_DQ8: U_A1.A13; also elsewhere on the board
A1_CH0_DQ9: U_A1.A14; also elsewhere on the board
A1_CH0_DQ10: U_A1.A15; also elsewhere on the board
A1_CH0_DQ11: U_A1.A16; also elsewhere on the board
A1_CH0_DQ12: U_A1.A17; also elsewhere on the board
A1_CH0_DQ13: U_A1.A18; also elsewhere on the board
A1_CH0_DQ14: U_A1.A19; also elsewhere on the board
A1_CH0_DQ15: U_A1.A20; also elsewhere on the board
A1_CH0_DQ16: U_A1.A25; also elsewhere on the board
A1_CH0_DQ17: U_A1.A26; also elsewhere on the board
A1_CH0_DQ18: U_A1.A27; also elsewhere on the board
A1_CH0_DQ19: U_A1.A28; also elsewhere on the board
A1_CH0_DQ20: U_A1.A29; also elsewhere on the board
A1_CH0_DQ21: U_A1.A30; also elsewhere on the board
A1_CH0_DQ22: U_A1.A31; also elsewhere on the board
A1_CH0_DQ23: U_A1.A32; also elsewhere on the board
A1_CH0_DQ24: U_A1.B2; also elsewhere on the board
A1_CH0_DQ25: U_A1.B3; also elsewhere on the board
A1_CH0_DQ26: U_A1.B4; also elsewhere on the board
A1_CH0_DQ27: U_A1.B5; also elsewhere on the board
A1_CH0_DQ28: U_A1.B6; also elsewhere on the board
A1_CH0_DQ29: U_A1.B7; also elsewhere on the board
A1_CH0_DQ30: U_A1.B8; also elsewhere on the board
A1_CH0_DQ31: U_A1.B9; also elsewhere on the board
A1_CH0_DQS0_N: U_A1.A10; also elsewhere on the board
A1_CH0_DQS0_P: U_A1.A9; also elsewhere on the board
A1_CH0_DQS1_N: U_A1.A22; also elsewhere on the board
A1_CH0_DQS1_P: U_A1.A21; also elsewhere on the board
A1_CH0_DQS2_N: U_A1.A34; also elsewhere on the board
A1_CH0_DQS2_P: U_A1.A33; also elsewhere on the board
A1_CH0_DQS3_N: U_A1.B11; also elsewhere on the board
A1_CH0_DQS3_P: U_A1.B10; also elsewhere on the board
A1_CH0_RESET: U_A1.B34; also elsewhere on the board
A1_CH1_CA0: U_A1.D14; also elsewhere on the board
A1_CH1_CA1: U_A1.D15; also elsewhere on the board
A1_CH1_CA2: U_A1.D16; also elsewhere on the board
A1_CH1_CA3: U_A1.D17; also elsewhere on the board
A1_CH1_CA4: U_A1.D18; also elsewhere on the board
A1_CH1_CA5: U_A1.D19; also elsewhere on the board
A1_CH1_CA6: U_A1.D20; also elsewhere on the board
A1_CH1_CA7: U_A1.D21; also elsewhere on the board
A1_CH1_CA8: U_A1.D22; also elsewhere on the board
A1_CH1_CA9: U_A1.D23; also elsewhere on the board
A1_CH1_CA10: U_A1.D24; also elsewhere on the board
A1_CH1_CA11: U_A1.D25; also elsewhere on the board
A1_CH1_CA12: U_A1.D26; also elsewhere on the board
A1_CH1_CA13: U_A1.D27; also elsewhere on the board
A1_CH1_CK0_N: U_A1.D31; also elsewhere on the board
A1_CH1_CK0_P: U_A1.D30; also elsewhere on the board
A1_CH1_CK1_N: U_A1.D33; also elsewhere on the board
A1_CH1_CK1_P: U_A1.D32; also elsewhere on the board
A1_CH1_CS0: U_A1.D28; also elsewhere on the board
A1_CH1_CS1: U_A1.D29; also elsewhere on the board
A1_CH1_DMI0: U_A1.C11; also elsewhere on the board
A1_CH1_DMI1: U_A1.C23; also elsewhere on the board
A1_CH1_DMI2: U_A1.C35; also elsewhere on the board
A1_CH1_DMI3: U_A1.D12; also elsewhere on the board
A1_CH1_DQ0: U_A1.C1; also elsewhere on the board
A1_CH1_DQ1: U_A1.C2; also elsewhere on the board
A1_CH1_DQ2: U_A1.C3; also elsewhere on the board
A1_CH1_DQ3: U_A1.C4; also elsewhere on the board
A1_CH1_DQ4: U_A1.C5; also elsewhere on the board
A1_CH1_DQ5: U_A1.C6; also elsewhere on the board
A1_CH1_DQ6: U_A1.C7; also elsewhere on the board
A1_CH1_DQ7: U_A1.C8; also elsewhere on the board
A1_CH1_DQ8: U_A1.C13; also elsewhere on the board
A1_CH1_DQ9: U_A1.C14; also elsewhere on the board
A1_CH1_DQ10: U_A1.C15; also elsewhere on the board
A1_CH1_DQ11: U_A1.C16; also elsewhere on the board
A1_CH1_DQ12: U_A1.C17; also elsewhere on the board
A1_CH1_DQ13: U_A1.C18; also elsewhere on the board
A1_CH1_DQ14: U_A1.C19; also elsewhere on the board
A1_CH1_DQ15: U_A1.C20; also elsewhere on the board
A1_CH1_DQ16: U_A1.C25; also elsewhere on the board
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

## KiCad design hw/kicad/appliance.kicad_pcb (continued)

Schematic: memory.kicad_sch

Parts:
U_D0, U_D1, U_D2, U_D3: DDR4 x16; FBGA96_8x12_P0.8
U_M0a, U_M0b, U_M1a, U_M1b, U_M2a, U_M2b, U_M3a, U_M3b, U_M4a, U_M4b, U_M5a, U_M5b, U_M6a, U_M6b, U_M7a, U_M7b: LPDDR5X x32; FBGA315_15x21_P0.8

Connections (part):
A0_CH0_CA0: U_M0a.W15; also elsewhere on the board
A0_CH0_CA1: U_M0a.V1; also elsewhere on the board
A0_CH0_CA2: U_M0a.V2; also elsewhere on the board
A0_CH0_CA3: U_M0a.V3; also elsewhere on the board
A0_CH0_CA4: U_M0a.V4; also elsewhere on the board
A0_CH0_CA5: U_M0a.V5; also elsewhere on the board
A0_CH0_CA6: U_M0a.V6; also elsewhere on the board
A0_CH0_CA7: U_M0a.V7; also elsewhere on the board
A0_CH0_CA8: U_M0a.V8; also elsewhere on the board
A0_CH0_CA9: U_M0a.V9; also elsewhere on the board
A0_CH0_CA10: U_M0a.V10; also elsewhere on the board
A0_CH0_CA11: U_M0a.V11; also elsewhere on the board
A0_CH0_CA12: U_M0a.V12; also elsewhere on the board
A0_CH0_CA13: U_M0a.V13; also elsewhere on the board
A0_CH0_CK0_N: U_M0a.U2; also elsewhere on the board
A0_CH0_CK0_P: U_M0a.U1; also elsewhere on the board
A0_CH0_CK1_N: U_M0a.U4; also elsewhere on the board
A0_CH0_CK1_P: U_M0a.U3; also elsewhere on the board
A0_CH0_CS0: U_M0a.V14; also elsewhere on the board
A0_CH0_CS1: U_M0a.V15; also elsewhere on the board
A0_CH0_DMI0: U_M0a.W11; also elsewhere on the board
A0_CH0_DMI1: U_M0a.W12; also elsewhere on the board
A0_CH0_DMI2: U_M0a.W13; also elsewhere on the board
A0_CH0_DMI3: U_M0a.W14; also elsewhere on the board
A0_CH0_DQ0: U_M0a.AA1; also elsewhere on the board
A0_CH0_DQ1: U_M0a.AA2; also elsewhere on the board
A0_CH0_DQ2: U_M0a.AA3; also elsewhere on the board
A0_CH0_DQ3: U_M0a.AA4; also elsewhere on the board
A0_CH0_DQ4: U_M0a.AA5; also elsewhere on the board
A0_CH0_DQ5: U_M0a.AA6; also elsewhere on the board
A0_CH0_DQ6: U_M0a.AA7; also elsewhere on the board
A0_CH0_DQ7: U_M0a.AA8; also elsewhere on the board
A0_CH0_DQ8: U_M0a.AA9; also elsewhere on the board
A0_CH0_DQ9: U_M0a.AA10; also elsewhere on the board
A0_CH0_DQ10: U_M0a.AA11; also elsewhere on the board
A0_CH0_DQ11: U_M0a.AA12; also elsewhere on the board
A0_CH0_DQ12: U_M0a.AA13; also elsewhere on the board
A0_CH0_DQ13: U_M0a.AA14; also elsewhere on the board
A0_CH0_DQ14: U_M0a.AA15; also elsewhere on the board
A0_CH0_DQ15: U_M0a.Y1; also elsewhere on the board
A0_CH0_DQ16: U_M0a.Y2; also elsewhere on the board
A0_CH0_DQ17: U_M0a.Y3; also elsewhere on the board
A0_CH0_DQ18: U_M0a.Y4; also elsewhere on the board
A0_CH0_DQ19: U_M0a.Y5; also elsewhere on the board
A0_CH0_DQ20: U_M0a.Y6; also elsewhere on the board
A0_CH0_DQ21: U_M0a.Y7; also elsewhere on the board
A0_CH0_DQ22: U_M0a.Y8; also elsewhere on the board
A0_CH0_DQ23: U_M0a.Y9; also elsewhere on the board
A0_CH0_DQ24: U_M0a.Y10; also elsewhere on the board
A0_CH0_DQ25: U_M0a.Y11; also elsewhere on the board
A0_CH0_DQ26: U_M0a.Y12; also elsewhere on the board
A0_CH0_DQ27: U_M0a.Y13; also elsewhere on the board
A0_CH0_DQ28: U_M0a.Y14; also elsewhere on the board
A0_CH0_DQ29: U_M0a.Y15; also elsewhere on the board
A0_CH0_DQ30: U_M0a.W1; also elsewhere on the board
A0_CH0_DQ31: U_M0a.W2; also elsewhere on the board
A0_CH0_DQS0_N: U_M0a.W4; also elsewhere on the board
A0_CH0_DQS0_P: U_M0a.W3; also elsewhere on the board
A0_CH0_DQS1_N: U_M0a.W6; also elsewhere on the board
A0_CH0_DQS1_P: U_M0a.W5; also elsewhere on the board
A0_CH0_DQS2_N: U_M0a.W8; also elsewhere on the board
A0_CH0_DQS2_P: U_M0a.W7; also elsewhere on the board
A0_CH0_DQS3_N: U_M0a.W10; also elsewhere on the board
A0_CH0_DQS3_P: U_M0a.W9; also elsewhere on the board
A0_CH0_RESET: U_M0a.U5; also elsewhere on the board
A0_CH1_CA0: U_M0b.W15; also elsewhere on the board
A0_CH1_CA1: U_M0b.V1; also elsewhere on the board
A0_CH1_CA2: U_M0b.V2; also elsewhere on the board
A0_CH1_CA3: U_M0b.V3; also elsewhere on the board
A0_CH1_CA4: U_M0b.V4; also elsewhere on the board
A0_CH1_CA5: U_M0b.V5; also elsewhere on the board
A0_CH1_CA6: U_M0b.V6; also elsewhere on the board
A0_CH1_CA7: U_M0b.V7; also elsewhere on the board
A0_CH1_CA8: U_M0b.V8; also elsewhere on the board
A0_CH1_CA9: U_M0b.V9; also elsewhere on the board
A0_CH1_CA10: U_M0b.V10; also elsewhere on the board
A0_CH1_CA11: U_M0b.V11; also elsewhere on the board
A0_CH1_CA12: U_M0b.V12; also elsewhere on the board
A0_CH1_CA13: U_M0b.V13; also elsewhere on the board
A0_CH1_CK0_N: U_M0b.U2; also elsewhere on the board
A0_CH1_CK0_P: U_M0b.U1; also elsewhere on the board
A0_CH1_CK1_N: U_M0b.U4; also elsewhere on the board
A0_CH1_CK1_P: U_M0b.U3; also elsewhere on the board
A0_CH1_CS0: U_M0b.V14; also elsewhere on the board
A0_CH1_CS1: U_M0b.V15; also elsewhere on the board
A0_CH1_DMI0: U_M0b.W11; also elsewhere on the board
A0_CH1_DMI1: U_M0b.W12; also elsewhere on the board
A0_CH1_DMI2: U_M0b.W13; also elsewhere on the board
A0_CH1_DMI3: U_M0b.W14; also elsewhere on the board
A0_CH1_DQ0: U_M0b.AA1; also elsewhere on the board
A0_CH1_DQ1: U_M0b.AA2; also elsewhere on the board
A0_CH1_DQ2: U_M0b.AA3; also elsewhere on the board
A0_CH1_DQ3: U_M0b.AA4; also elsewhere on the board
A0_CH1_DQ4: U_M0b.AA5; also elsewhere on the board
A0_CH1_DQ5: U_M0b.AA6; also elsewhere on the board
A0_CH1_DQ6: U_M0b.AA7; also elsewhere on the board
A0_CH1_DQ7: U_M0b.AA8; also elsewhere on the board
A0_CH1_DQ8: U_M0b.AA9; also elsewhere on the board
A0_CH1_DQ9: U_M0b.AA10; also elsewhere on the board
A0_CH1_DQ10: U_M0b.AA11; also elsewhere on the board
A0_CH1_DQ11: U_M0b.AA12; also elsewhere on the board
A0_CH1_DQ12: U_M0b.AA13; also elsewhere on the board
A0_CH1_DQ13: U_M0b.AA14; also elsewhere on the board
A0_CH1_DQ14: U_M0b.AA15; also elsewhere on the board
A0_CH1_DQ15: U_M0b.Y1; also elsewhere on the board
A0_CH1_DQ16: U_M0b.Y2; also elsewhere on the board
A0_CH1_DQ17: U_M0b.Y3; also elsewhere on the board
A0_CH1_DQ18: U_M0b.Y4; also elsewhere on the board
A0_CH1_DQ19: U_M0b.Y5; also elsewhere on the board
A0_CH1_DQ20: U_M0b.Y6; also elsewhere on the board
A0_CH1_DQ21: U_M0b.Y7; also elsewhere on the board
A0_CH1_DQ22: U_M0b.Y8; also elsewhere on the board
A0_CH1_DQ23: U_M0b.Y9; also elsewhere on the board
A0_CH1_DQ24: U_M0b.Y10; also elsewhere on the board
A0_CH1_DQ25: U_M0b.Y11; also elsewhere on the board
A0_CH1_DQ26: U_M0b.Y12; also elsewhere on the board
A0_CH1_DQ27: U_M0b.Y13; also elsewhere on the board
A0_CH1_DQ28: U_M0b.Y14; also elsewhere on the board
A0_CH1_DQ29: U_M0b.Y15; also elsewhere on the board
A0_CH1_DQ30: U_M0b.W1; also elsewhere on the board
A0_CH1_DQ31: U_M0b.W2; also elsewhere on the board
A0_CH1_DQS0_N: U_M0b.W4; also elsewhere on the board
A0_CH1_DQS0_P: U_M0b.W3; also elsewhere on the board
A0_CH1_DQS1_N: U_M0b.W6; also elsewhere on the board
A0_CH1_DQS1_P: U_M0b.W5; also elsewhere on the board
A0_CH1_DQS2_N: U_M0b.W8; also elsewhere on the board
A0_CH1_DQS2_P: U_M0b.W7; also elsewhere on the board
A0_CH1_DQS3_N: U_M0b.W10; also elsewhere on the board
A0_CH1_DQS3_P: U_M0b.W9; also elsewhere on the board
A0_CH1_RESET: U_M0b.U5; also elsewhere on the board
A1_CH0_CA0: U_M1a.W15; also elsewhere on the board
A1_CH0_CA1: U_M1a.V1; also elsewhere on the board
A1_CH0_CA2: U_M1a.V2; also elsewhere on the board
A1_CH0_CA3: U_M1a.V3; also elsewhere on the board
A1_CH0_CA4: U_M1a.V4; also elsewhere on the board
A1_CH0_CA5: U_M1a.V5; also elsewhere on the board
A1_CH0_CA6: U_M1a.V6; also elsewhere on the board
A1_CH0_CA7: U_M1a.V7; also elsewhere on the board
A1_CH0_CA8: U_M1a.V8; also elsewhere on the board
A1_CH0_CA9: U_M1a.V9; also elsewhere on the board
A1_CH0_CA10: U_M1a.V10; also elsewhere on the board
A1_CH0_CA11: U_M1a.V11; also elsewhere on the board
A1_CH0_CA12: U_M1a.V12; also elsewhere on the board
A1_CH0_CA13: U_M1a.V13; also elsewhere on the board
A1_CH0_CK0_N: U_M1a.U2; also elsewhere on the board
A1_CH0_CK0_P: U_M1a.U1; also elsewhere on the board
A1_CH0_CK1_N: U_M1a.U4; also elsewhere on the board
A1_CH0_CK1_P: U_M1a.U3; also elsewhere on the board
A1_CH0_CS0: U_M1a.V14; also elsewhere on the board
A1_CH0_CS1: U_M1a.V15; also elsewhere on the board
A1_CH0_DMI0: U_M1a.W11; also elsewhere on the board
A1_CH0_DMI1: U_M1a.W12; also elsewhere on the board
A1_CH0_DMI2: U_M1a.W13; also elsewhere on the board
A1_CH0_DMI3: U_M1a.W14; also elsewhere on the board
A1_CH0_DQ0: U_M1a.AA1; also elsewhere on the board
A1_CH0_DQ1: U_M1a.AA2; also elsewhere on the board
A1_CH0_DQ2: U_M1a.AA3; also elsewhere on the board
A1_CH0_DQ3: U_M1a.AA4; also elsewhere on the board
A1_CH0_DQ4: U_M1a.AA5; also elsewhere on the board
A1_CH0_DQ5: U_M1a.AA6; also elsewhere on the board
A1_CH0_DQ6: U_M1a.AA7; also elsewhere on the board
A1_CH0_DQ7: U_M1a.AA8; also elsewhere on the board
A1_CH0_DQ8: U_M1a.AA9; also elsewhere on the board
A1_CH0_DQ9: U_M1a.AA10; also elsewhere on the board
A1_CH0_DQ10: U_M1a.AA11; also elsewhere on the board
A1_CH0_DQ11: U_M1a.AA12; also elsewhere on the board
A1_CH0_DQ12: U_M1a.AA13; also elsewhere on the board
A1_CH0_DQ13: U_M1a.AA14; also elsewhere on the board
A1_CH0_DQ14: U_M1a.AA15; also elsewhere on the board
A1_CH0_DQ15: U_M1a.Y1; also elsewhere on the board
A1_CH0_DQ16: U_M1a.Y2; also elsewhere on the board
A1_CH0_DQ17: U_M1a.Y3; also elsewhere on the board
A1_CH0_DQ18: U_M1a.Y4; also elsewhere on the board
A1_CH0_DQ19: U_M1a.Y5; also elsewhere on the board
A1_CH0_DQ20: U_M1a.Y6; also elsewhere on the board
A1_CH0_DQ21: U_M1a.Y7; also elsewhere on the board
A1_CH0_DQ22: U_M1a.Y8; also elsewhere on the board
A1_CH0_DQ23: U_M1a.Y9; also elsewhere on the board
A1_CH0_DQ24: U_M1a.Y10; also elsewhere on the board
A1_CH0_DQ25: U_M1a.Y11; also elsewhere on the board
A1_CH0_DQ26: U_M1a.Y12; also elsewhere on the board
A1_CH0_DQ27: U_M1a.Y13; also elsewhere on the board
A1_CH0_DQ28: U_M1a.Y14; also elsewhere on the board
A1_CH0_DQ29: U_M1a.Y15; also elsewhere on the board
A1_CH0_DQ30: U_M1a.W1; also elsewhere on the board
A1_CH0_DQ31: U_M1a.W2; also elsewhere on the board
A1_CH0_DQS0_N: U_M1a.W4; also elsewhere on the board
A1_CH0_DQS0_P: U_M1a.W3; also elsewhere on the board
A1_CH0_DQS1_N: U_M1a.W6; also elsewhere on the board
A1_CH0_DQS1_P: U_M1a.W5; also elsewhere on the board
A1_CH0_DQS2_N: U_M1a.W8; also elsewhere on the board
A1_CH0_DQS2_P: U_M1a.W7; also elsewhere on the board
A1_CH0_DQS3_N: U_M1a.W10; also elsewhere on the board
A1_CH0_DQS3_P: U_M1a.W9; also elsewhere on the board
A1_CH0_RESET: U_M1a.U5; also elsewhere on the board
A1_CH1_CA0: U_M1b.W15; also elsewhere on the board
A1_CH1_CA1: U_M1b.V1; also elsewhere on the board
A1_CH1_CA2: U_M1b.V2; also elsewhere on the board
A1_CH1_CA3: U_M1b.V3; also elsewhere on the board
A1_CH1_CA4: U_M1b.V4; also elsewhere on the board
A1_CH1_CA5: U_M1b.V5; also elsewhere on the board
A1_CH1_CA6: U_M1b.V6; also elsewhere on the board
A1_CH1_CA7: U_M1b.V7; also elsewhere on the board
A1_CH1_CA8: U_M1b.V8; also elsewhere on the board
A1_CH1_CA9: U_M1b.V9; also elsewhere on the board
A1_CH1_CA10: U_M1b.V10; also elsewhere on the board
A1_CH1_CA11: U_M1b.V11; also elsewhere on the board
A1_CH1_CA12: U_M1b.V12; also elsewhere on the board
A1_CH1_CA13: U_M1b.V13; also elsewhere on the board
A1_CH1_CK0_N: U_M1b.U2; also elsewhere on the board
A1_CH1_CK0_P: U_M1b.U1; also elsewhere on the board
A1_CH1_CK1_N: U_M1b.U4; also elsewhere on the board
A1_CH1_CK1_P: U_M1b.U3; also elsewhere on the board
A1_CH1_CS0: U_M1b.V14; also elsewhere on the board
A1_CH1_CS1: U_M1b.V15; also elsewhere on the board
A1_CH1_DMI0: U_M1b.W11; also elsewhere on the board
A1_CH1_DMI1: U_M1b.W12; also elsewhere on the board
A1_CH1_DMI2: U_M1b.W13; also elsewhere on the board
A1_CH1_DMI3: U_M1b.W14; also elsewhere on the board
A1_CH1_DQ0: U_M1b.AA1; also elsewhere on the board
A1_CH1_DQ1: U_M1b.AA2; also elsewhere on the board
A1_CH1_DQ2: U_M1b.AA3; also elsewhere on the board
A1_CH1_DQ3: U_M1b.AA4; also elsewhere on the board
A1_CH1_DQ4: U_M1b.AA5; also elsewhere on the board
A1_CH1_DQ5: U_M1b.AA6; also elsewhere on the board
A1_CH1_DQ6: U_M1b.AA7; also elsewhere on the board
A1_CH1_DQ7: U_M1b.AA8; also elsewhere on the board
A1_CH1_DQ8: U_M1b.AA9; also elsewhere on the board
A1_CH1_DQ9: U_M1b.AA10; also elsewhere on the board
A1_CH1_DQ10: U_M1b.AA11; also elsewhere on the board
A1_CH1_DQ11: U_M1b.AA12; also elsewhere on the board
A1_CH1_DQ12: U_M1b.AA13; also elsewhere on the board
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

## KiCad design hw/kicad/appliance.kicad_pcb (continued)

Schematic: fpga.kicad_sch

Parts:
J_BMC_NET: BMC Ethernet; RJ45_MAGJACK
J_HOST: SlimSAS 8i host cable; SLIMSAS_8I
J_SFP: SFP+ cage; SFP_CAGE
U_BMC: BMC SoC; BGA_BMC_21x21
U_CLK: Si5345; QFN64_9x9
U_FPGA: FPGA; FFVB676_26x26_P1.0

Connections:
BMC_ETH0_N: J_BMC_NET.2, U_BMC.2
BMC_ETH0_P: J_BMC_NET.1, U_BMC.1
BMC_ETH1_N: J_BMC_NET.4, U_BMC.4
BMC_ETH1_P: J_BMC_NET.3, U_BMC.3
BMC_ETH2_N: J_BMC_NET.6, U_BMC.6
BMC_ETH2_P: J_BMC_NET.5, U_BMC.5
BMC_ETH3_N: J_BMC_NET.8, U_BMC.8
BMC_ETH3_P: J_BMC_NET.7, U_BMC.7
DDR4_ADDR_CMD0: U_FPGA.D11; also elsewhere on the board
DDR4_ADDR_CMD1: U_FPGA.D12; also elsewhere on the board
DDR4_ADDR_CMD2: U_FPGA.D13; also elsewhere on the board
DDR4_ADDR_CMD3: U_FPGA.D14; also elsewhere on the board
DDR4_ADDR_CMD4: U_FPGA.D15; also elsewhere on the board
DDR4_ADDR_CMD5: U_FPGA.D16; also elsewhere on the board
DDR4_ADDR_CMD6: U_FPGA.D17; also elsewhere on the board
DDR4_ADDR_CMD7: U_FPGA.D18; also elsewhere on the board
DDR4_ADDR_CMD8: U_FPGA.D19; also elsewhere on the board
DDR4_ADDR_CMD9: U_FPGA.D20; also elsewhere on the board
DDR4_ADDR_CMD10: U_FPGA.D21; also elsewhere on the board
DDR4_ADDR_CMD11: U_FPGA.D22; also elsewhere on the board
DDR4_ADDR_CMD12: U_FPGA.D23; also elsewhere on the board
DDR4_ADDR_CMD13: U_FPGA.D24; also elsewhere on the board
DDR4_ADDR_CMD14: U_FPGA.D25; also elsewhere on the board
DDR4_ADDR_CMD15: U_FPGA.D26; also elsewhere on the board
DDR4_ADDR_CMD16: U_FPGA.E3; also elsewhere on the board
DDR4_ADDR_CMD17: U_FPGA.E4; also elsewhere on the board
DDR4_ADDR_CMD18: U_FPGA.E5; also elsewhere on the board
DDR4_ADDR_CMD19: U_FPGA.E6; also elsewhere on the board
DDR4_ADDR_CMD20: U_FPGA.E7; also elsewhere on the board
DDR4_ADDR_CMD21: U_FPGA.E8; also elsewhere on the board
DDR4_ADDR_CMD22: U_FPGA.E9; also elsewhere on the board
DDR4_ADDR_CMD23: U_FPGA.E10; also elsewhere on the board
DDR4_ADDR_CMD24: U_FPGA.E11; also elsewhere on the board
DDR4_ADDR_CMD25: U_FPGA.E12; also elsewhere on the board
DDR4_ADDR_CMD26: U_FPGA.E13; also elsewhere on the board
DDR4_ADDR_CMD27: U_FPGA.E14; also elsewhere on the board
DDR4_CK_N: U_FPGA.E16; also elsewhere on the board
DDR4_CK_P: U_FPGA.E15; also elsewhere on the board
DDR4_CTRL0: U_FPGA.E17; also elsewhere on the board
DDR4_CTRL1: U_FPGA.E18; also elsewhere on the board
DDR4_CTRL2: U_FPGA.E19; also elsewhere on the board
DDR4_CTRL3: U_FPGA.E20; also elsewhere on the board
DDR4_CTRL4: U_FPGA.E21; also elsewhere on the board
DDR4_CTRL5: U_FPGA.E22; also elsewhere on the board
DDR4_DM0: U_FPGA.D3; also elsewhere on the board
DDR4_DM1: U_FPGA.D4; also elsewhere on the board
DDR4_DM2: U_FPGA.D5; also elsewhere on the board
DDR4_DM3: U_FPGA.D6; also elsewhere on the board
DDR4_DM4: U_FPGA.D7; also elsewhere on the board
DDR4_DM5: U_FPGA.D8; also elsewhere on the board
DDR4_DM6: U_FPGA.D9; also elsewhere on the board
DDR4_DM7: U_FPGA.D10; also elsewhere on the board
DDR4_DQ0: U_FPGA.A1; also elsewhere on the board
DDR4_DQ1: U_FPGA.A2; also elsewhere on the board
DDR4_DQ2: U_FPGA.A3; also elsewhere on the board
DDR4_DQ3: U_FPGA.A4; also elsewhere on the board
DDR4_DQ4: U_FPGA.A5; also elsewhere on the board
DDR4_DQ5: U_FPGA.A6; also elsewhere on the board
DDR4_DQ6: U_FPGA.A7; also elsewhere on the board
DDR4_DQ7: U_FPGA.A8; also elsewhere on the board
DDR4_DQ8: U_FPGA.A9; also elsewhere on the board
DDR4_DQ9: U_FPGA.A10; also elsewhere on the board
DDR4_DQ10: U_FPGA.A11; also elsewhere on the board
DDR4_DQ11: U_FPGA.A12; also elsewhere on the board
DDR4_DQ12: U_FPGA.A13; also elsewhere on the board
DDR4_DQ13: U_FPGA.A14; also elsewhere on the board
DDR4_DQ14: U_FPGA.A15; also elsewhere on the board
DDR4_DQ15: U_FPGA.A16; also elsewhere on the board
DDR4_DQ16: U_FPGA.A17; also elsewhere on the board
DDR4_DQ17: U_FPGA.A18; also elsewhere on the board
DDR4_DQ18: U_FPGA.A19; also elsewhere on the board
DDR4_DQ19: U_FPGA.A20; also elsewhere on the board
DDR4_DQ20: U_FPGA.A21; also elsewhere on the board
DDR4_DQ21: U_FPGA.A22; also elsewhere on the board
DDR4_DQ22: U_FPGA.A23; also elsewhere on the board
DDR4_DQ23: U_FPGA.A24; also elsewhere on the board
DDR4_DQ24: U_FPGA.A25; also elsewhere on the board
DDR4_DQ25: U_FPGA.A26; also elsewhere on the board
DDR4_DQ26: U_FPGA.B1; also elsewhere on the board
DDR4_DQ27: U_FPGA.B2; also elsewhere on the board
DDR4_DQ28: U_FPGA.B3; also elsewhere on the board
DDR4_DQ29: U_FPGA.B4; also elsewhere on the board
DDR4_DQ30: U_FPGA.B5; also elsewhere on the board
DDR4_DQ31: U_FPGA.B6; also elsewhere on the board
DDR4_DQ32: U_FPGA.B7; also elsewhere on the board
DDR4_DQ33: U_FPGA.B8; also elsewhere on the board
DDR4_DQ34: U_FPGA.B9; also elsewhere on the board
DDR4_DQ35: U_FPGA.B10; also elsewhere on the board
DDR4_DQ36: U_FPGA.B11; also elsewhere on the board
DDR4_DQ37: U_FPGA.B12; also elsewhere on the board
DDR4_DQ38: U_FPGA.B13; also elsewhere on the board
DDR4_DQ39: U_FPGA.B14; also elsewhere on the board
DDR4_DQ40: U_FPGA.B15; also elsewhere on the board
DDR4_DQ41: U_FPGA.B16; also elsewhere on the board
DDR4_DQ42: U_FPGA.B17; also elsewhere on the board
DDR4_DQ43: U_FPGA.B18; also elsewhere on the board
DDR4_DQ44: U_FPGA.B19; also elsewhere on the board
DDR4_DQ45: U_FPGA.B20; also elsewhere on the board
DDR4_DQ46: U_FPGA.B21; also elsewhere on the board
DDR4_DQ47: U_FPGA.B22; also elsewhere on the board
DDR4_DQ48: U_FPGA.B23; also elsewhere on the board
DDR4_DQ49: U_FPGA.B24; also elsewhere on the board
DDR4_DQ50: U_FPGA.B25; also elsewhere on the board
DDR4_DQ51: U_FPGA.B26; also elsewhere on the board
DDR4_DQ52: U_FPGA.C1; also elsewhere on the board
DDR4_DQ53: U_FPGA.C2; also elsewhere on the board
DDR4_DQ54: U_FPGA.C3; also elsewhere on the board
DDR4_DQ55: U_FPGA.C4; also elsewhere on the board
DDR4_DQ56: U_FPGA.C5; also elsewhere on the board
DDR4_DQ57: U_FPGA.C6; also elsewhere on the board
DDR4_DQ58: U_FPGA.C7; also elsewhere on the board
DDR4_DQ59: U_FPGA.C8; also elsewhere on the board
DDR4_DQ60: U_FPGA.C9; also elsewhere on the board
DDR4_DQ61: U_FPGA.C10; also elsewhere on the board
DDR4_DQ62: U_FPGA.C11; also elsewhere on the board
DDR4_DQ63: U_FPGA.C12; also elsewhere on the board
DDR4_DQS0_N: U_FPGA.C14; also elsewhere on the board
DDR4_DQS0_P: U_FPGA.C13; also elsewhere on the board
DDR4_DQS1_N: U_FPGA.C16; also elsewhere on the board
DDR4_DQS1_P: U_FPGA.C15; also elsewhere on the board
DDR4_DQS2_N: U_FPGA.C18; also elsewhere on the board
DDR4_DQS2_P: U_FPGA.C17; also elsewhere on the board
DDR4_DQS3_N: U_FPGA.C20; also elsewhere on the board
DDR4_DQS3_P: U_FPGA.C19; also elsewhere on the board
DDR4_DQS4_N: U_FPGA.C22; also elsewhere on the board
DDR4_DQS4_P: U_FPGA.C21; also elsewhere on the board
DDR4_DQS5_N: U_FPGA.C24; also elsewhere on the board
DDR4_DQS5_P: U_FPGA.C23; also elsewhere on the board
DDR4_DQS6_N: U_FPGA.C26; also elsewhere on the board
DDR4_DQS6_P: U_FPGA.C25; also elsewhere on the board
DDR4_DQS7_N: U_FPGA.D2; also elsewhere on the board
DDR4_DQS7_P: U_FPGA.D1; also elsewhere on the board
FAN_0_PWM: U_BMC.9; also elsewhere on the board
FAN_0_TACH: U_BMC.10; also elsewhere on the board
FAN_1_PWM: U_BMC.11; also elsewhere on the board
FAN_1_TACH: U_BMC.12; also elsewhere on the board
FAN_2_PWM: U_BMC.13; also elsewhere on the board
FAN_2_TACH: U_BMC.14; also elsewhere on the board
FAN_3_PWM: U_BMC.15; also elsewhere on the board
FAN_3_TACH: U_BMC.16; also elsewhere on the board
FAN_4_PWM: U_BMC.17; also elsewhere on the board
FAN_4_TACH: U_BMC.18; also elsewhere on the board
FAN_5_PWM: U_BMC.19; also elsewhere on the board
FAN_5_TACH: U_BMC.20; also elsewhere on the board
GND: J_BMC_NET.10, J_BMC_NET.11, J_BMC_NET.12, J_HOST.37, J_HOST.38, J_HOST.39, J_HOST.40, J_HOST.41, J_HOST.42, J_HOST.43, J_HOST.44, J_HOST.45, J_HOST.46, J_HOST.47, J_HOST.48, J_HOST.49, J_HOST.50, J_HOST.51, J_HOST.52, J_HOST.53, J_HOST.54, J_SFP.13, J_SFP.14, J_SFP.15, J_SFP.16, U_BMC.28, U_BMC.29, U_CLK.2, U_FPGA.AA3, U_FPGA.AA5, U_FPGA.AA7, U_FPGA.AA9, U_FPGA.AA11, U_FPGA.AA13, U_FPGA.AA15, U_FPGA.AA17, U_FPGA.AA19, U_FPGA.AA21, U_FPGA.AA23, U_FPGA.AB4, U_FPGA.AB6, U_FPGA.AB8, U_FPGA.AB10, U_FPGA.AB12, U_FPGA.AB14, U_FPGA.AB16, U_FPGA.AB18, U_FPGA.AB20, U_FPGA.AB22, U_FPGA.AB24, U_FPGA.AC25, U_FPGA.AD26, U_FPGA.AE1, U_FPGA.AE17, U_FPGA.AE19, U_FPGA.AE21, U_FPGA.AE23, U_FPGA.AE25, U_FPGA.AF2, U_FPGA.AF26, U_FPGA.E23, U_FPGA.F4, U_FPGA.F6, U_FPGA.F8, U_FPGA.F10, U_FPGA.F12, U_FPGA.F14, U_FPGA.F16, U_FPGA.F18, U_FPGA.F20, U_FPGA.F22, U_FPGA.F24, U_FPGA.G3, U_FPGA.G5, U_FPGA.G7, U_FPGA.G9, U_FPGA.G11, U_FPGA.G13, U_FPGA.G15, U_FPGA.G17, U_FPGA.G19, U_FPGA.G21, U_FPGA.G23, U_FPGA.H4, U_FPGA.H6, U_FPGA.H8, U_FPGA.H10, U_FPGA.H12, U_FPGA.H14, U_FPGA.H16, U_FPGA.H18, U_FPGA.H20, U_FPGA.H22, U_FPGA.H24, U_FPGA.J3, U_FPGA.J5, U_FPGA.J7, U_FPGA.J9, U_FPGA.J11, U_FPGA.J13, U_FPGA.J15, U_FPGA.J17, U_FPGA.J19, U_FPGA.J21, U_FPGA.J23, U_FPGA.K4, U_FPGA.K6, U_FPGA.K8, U_FPGA.K10, U_FPGA.K12, U_FPGA.K14, U_FPGA.K16, U_FPGA.K18, U_FPGA.K20, U_FPGA.K22, U_FPGA.K24, U_FPGA.L3, U_FPGA.L5, U_FPGA.L7, U_FPGA.L9, U_FPGA.L11, U_FPGA.L13, U_FPGA.L15, U_FPGA.L17, U_FPGA.L19, U_FPGA.L21, U_FPGA.L23, U_FPGA.M4, U_FPGA.M6, U_FPGA.M8, U_FPGA.M10, U_FPGA.M12, U_FPGA.M14, U_FPGA.M16, U_FPGA.M18, U_FPGA.M20, U_FPGA.M22, U_FPGA.M24, U_FPGA.N3, U_FPGA.N5, U_FPGA.N7, U_FPGA.N9, U_FPGA.N11, U_FPGA.N13, U_FPGA.N15, U_FPGA.N17, U_FPGA.N19, U_FPGA.N21, U_FPGA.N23, U_FPGA.P4, U_FPGA.P6, U_FPGA.P8, U_FPGA.P10, U_FPGA.P12, U_FPGA.P14, U_FPGA.P16, U_FPGA.P18, U_FPGA.P20, U_FPGA.P22, U_FPGA.P24, U_FPGA.R3, U_FPGA.R5, U_FPGA.R7, U_FPGA.R9, U_FPGA.R11, U_FPGA.R13, U_FPGA.R15, U_FPGA.R17, U_FPGA.R19, U_FPGA.R21, U_FPGA.R23, U_FPGA.T4, U_FPGA.T6, U_FPGA.T8, U_FPGA.T10, U_FPGA.T12, U_FPGA.T14, U_FPGA.T16, U_FPGA.T18, U_FPGA.T20, U_FPGA.T22, U_FPGA.T24, U_FPGA.U3, U_FPGA.U5, U_FPGA.U7, U_FPGA.U9, U_FPGA.U11, U_FPGA.U13, U_FPGA.U15, U_FPGA.U17, U_FPGA.U19, U_FPGA.U21, U_FPGA.U23, U_FPGA.V4, U_FPGA.V6, U_FPGA.V8, U_FPGA.V10, U_FPGA.V12, U_FPGA.V14, U_FPGA.V16, U_FPGA.V18, U_FPGA.V20, U_FPGA.V22, U_FPGA.V24, U_FPGA.W3, U_FPGA.W5, U_FPGA.W7, U_FPGA.W9, U_FPGA.W11, U_FPGA.W13, U_FPGA.W15, U_FPGA.W17, U_FPGA.W19, U_FPGA.W21, U_FPGA.W23, U_FPGA.Y4, U_FPGA.Y6, U_FPGA.Y8, U_FPGA.Y10, U_FPGA.Y12, U_FPGA.Y14, U_FPGA.Y16, U_FPGA.Y18, U_FPGA.Y20, U_FPGA.Y22, U_FPGA.Y24; also elsewhere on the board
JTAG_TCK: U_FPGA.AC24; also elsewhere on the board
JTAG_TDI_FPGA: U_FPGA.AD2
JTAG_TDO_FPGA: U_FPGA.AD3; also elsewhere on the board
JTAG_TMS: U_FPGA.AD1; also elsewhere on the board
JTAG_TRST: U_FPGA.AD4; also elsewhere on the board
LINK0_CLOCK: U_FPGA.AA26; also elsewhere on the board
LINK0_DATA0: U_FPGA.E26; also elsewhere on the board
LINK0_DATA1: U_FPGA.E25; also elsewhere on the board
LINK0_DATA2: U_FPGA.F26; also elsewhere on the board
LINK0_DATA3: U_FPGA.F25; also elsewhere on the board
LINK0_DATA4: U_FPGA.G26; also elsewhere on the board
LINK0_DATA5: U_FPGA.G25; also elsewhere on the board
LINK0_DATA6: U_FPGA.H26; also elsewhere on the board
LINK0_DATA7: U_FPGA.H25; also elsewhere on the board
LINK0_DATA8: U_FPGA.J26; also elsewhere on the board
LINK0_DATA9: U_FPGA.J25; also elsewhere on the board
LINK0_DATA10: U_FPGA.K26; also elsewhere on the board
LINK0_DATA11: U_FPGA.K25; also elsewhere on the board
LINK0_DATA12: U_FPGA.L26; also elsewhere on the board
LINK0_DATA13: U_FPGA.L25; also elsewhere on the board
LINK0_DATA14: U_FPGA.M26; also elsewhere on the board
LINK0_DATA15: U_FPGA.M25; also elsewhere on the board
LINK0_DATA16: U_FPGA.N26; also elsewhere on the board
LINK0_DATA17: U_FPGA.N25; also elsewhere on the board
LINK0_DATA18: U_FPGA.P26; also elsewhere on the board
LINK0_DATA19: U_FPGA.P25; also elsewhere on the board
LINK0_DATA20: U_FPGA.R26; also elsewhere on the board
LINK0_DATA21: U_FPGA.R25; also elsewhere on the board
LINK0_DATA22: U_FPGA.T26; also elsewhere on the board
LINK0_DATA23: U_FPGA.T25; also elsewhere on the board
LINK0_DATA24: U_FPGA.U26; also elsewhere on the board
LINK0_DATA25: U_FPGA.U25; also elsewhere on the board
LINK0_DATA26: U_FPGA.V26; also elsewhere on the board
LINK0_DATA27: U_FPGA.V25; also elsewhere on the board
LINK0_DATA28: U_FPGA.W26; also elsewhere on the board
LINK0_DATA29: U_FPGA.W25; also elsewhere on the board
LINK0_DATA30: U_FPGA.Y26; also elsewhere on the board
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

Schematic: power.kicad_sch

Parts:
J_FAN0, J_FAN1, J_FAN2, J_FAN3, J_FAN4, J_FAN5: fan header; FAN_4PIN
J_PSU0, J_PSU1: CRPS 12 V output; CRPS_BLADES
REG_0V3: VDDQ_0V3 regulator; REG_MODULE_20x6
REG_0V9: VDD2L_0V9 regulator; REG_MODULE_20x6
REG_1V05: VDD2H_1V05 regulator; REG_MODULE_20x6
REG_1V8: VDD_IO_1V8 regulator; REG_MODULE_20x6
REG_3V3: VDD_3V3 regulator; REG_MODULE_20x6
REG_DDR: VDD_1V2 regulator; REG_MODULE_20x6
REG_FPGA: VCCINT_0V85 regulator; REG_MODULE_20x6
VRM_A0: core VRM VDD_CORE_A0; VRM_MODULE_26x6
VRM_A1: core VRM VDD_CORE_A1; VRM_MODULE_26x6
VRM_A2: core VRM VDD_CORE_A2; VRM_MODULE_26x6
VRM_A3: core VRM VDD_CORE_A3; VRM_MODULE_26x6
VRM_A4: core VRM VDD_CORE_A4; VRM_MODULE_26x6
VRM_A5: core VRM VDD_CORE_A5; VRM_MODULE_26x6
VRM_A6: core VRM VDD_CORE_A6; VRM_MODULE_26x6
VRM_A7: core VRM VDD_CORE_A7; VRM_MODULE_26x6
VRM_H0: core VRM VDD_CORE_H0; VRM_MODULE_26x6
VRM_H1: core VRM VDD_CORE_H1; VRM_MODULE_26x6

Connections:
+12V: J_FAN0.1, J_FAN1.1, J_FAN2.1, J_FAN3.1, J_FAN4.1, J_FAN5.1, J_PSU0.1, J_PSU0.2, J_PSU0.3, J_PSU0.4, J_PSU0.5, J_PSU0.6, J_PSU1.1, J_PSU1.2, J_PSU1.3, J_PSU1.4, J_PSU1.5, J_PSU1.6, REG_0V3.1, REG_0V3.2, REG_0V3.3, REG_0V9.1, REG_0V9.2, REG_0V9.3, REG_1V05.1, REG_1V05.2, REG_1V05.3, REG_1V8.1, REG_1V8.2, REG_1V8.3, REG_3V3.1, REG_3V3.2, REG_3V3.3, REG_DDR.1, REG_DDR.2, REG_DDR.3, REG_FPGA.1, REG_FPGA.2, REG_FPGA.3, VRM_A0.1, VRM_A0.2, VRM_A0.3, VRM_A0.4, VRM_A1.1, VRM_A1.2, VRM_A1.3, VRM_A1.4, VRM_A2.1, VRM_A2.2, VRM_A2.3, VRM_A2.4, VRM_A3.1, VRM_A3.2, VRM_A3.3, VRM_A3.4, VRM_A4.1, VRM_A4.2, VRM_A4.3, VRM_A4.4, VRM_A5.1, VRM_A5.2, VRM_A5.3, VRM_A5.4, VRM_A6.1, VRM_A6.2, VRM_A6.3, VRM_A6.4, VRM_A7.1, VRM_A7.2, VRM_A7.3, VRM_A7.4, VRM_H0.1, VRM_H0.2, VRM_H0.3, VRM_H0.4, VRM_H1.1, VRM_H1.2, VRM_H1.3, VRM_H1.4
FAN_0_PWM: J_FAN0.3; also elsewhere on the board
FAN_0_TACH: J_FAN0.4; also elsewhere on the board
FAN_1_PWM: J_FAN1.3; also elsewhere on the board
FAN_1_TACH: J_FAN1.4; also elsewhere on the board
FAN_2_PWM: J_FAN2.3; also elsewhere on the board
FAN_2_TACH: J_FAN2.4; also elsewhere on the board
FAN_3_PWM: J_FAN3.3; also elsewhere on the board
FAN_3_TACH: J_FAN3.4; also elsewhere on the board
FAN_4_PWM: J_FAN4.3; also elsewhere on the board
FAN_4_TACH: J_FAN4.4; also elsewhere on the board
FAN_5_PWM: J_FAN5.3; also elsewhere on the board
FAN_5_TACH: J_FAN5.4; also elsewhere on the board
GND: J_FAN0.2, J_FAN1.2, J_FAN2.2, J_FAN3.2, J_FAN4.2, J_FAN5.2, J_PSU0.7, J_PSU0.8, J_PSU0.9, J_PSU0.10, J_PSU0.11, J_PSU0.12, J_PSU0.16, J_PSU1.7, J_PSU1.8, J_PSU1.9, J_PSU1.10, J_PSU1.11, J_PSU1.12, J_PSU1.16, REG_0V3.8, REG_0V3.9, REG_0V3.10, REG_0V9.8, REG_0V9.9, REG_0V9.10, REG_1V05.8, REG_1V05.9, REG_1V05.10, REG_1V8.8, REG_1V8.9, REG_1V8.10, REG_3V3.8, REG_3V3.9, REG_3V3.10, REG_DDR.8, REG_DDR.9, REG_DDR.10, REG_FPGA.8, REG_FPGA.9, REG_FPGA.10, VRM_A0.11, VRM_A0.12, VRM_A0.13, VRM_A0.14, VRM_A0.15, VRM_A0.16, VRM_A1.11, VRM_A1.12, VRM_A1.13, VRM_A1.14, VRM_A1.15, VRM_A1.16, VRM_A2.11, VRM_A2.12, VRM_A2.13, VRM_A2.14, VRM_A2.15, VRM_A2.16, VRM_A3.11, VRM_A3.12, VRM_A3.13, VRM_A3.14, VRM_A3.15, VRM_A3.16, VRM_A4.11, VRM_A4.12, VRM_A4.13, VRM_A4.14, VRM_A4.15, VRM_A4.16, VRM_A5.11, VRM_A5.12, VRM_A5.13, VRM_A5.14, VRM_A5.15, VRM_A5.16, VRM_A6.11, VRM_A6.12, VRM_A6.13, VRM_A6.14, VRM_A6.15, VRM_A6.16, VRM_A7.11, VRM_A7.12, VRM_A7.13, VRM_A7.14, VRM_A7.15, VRM_A7.16, VRM_H0.11, VRM_H0.12, VRM_H0.13, VRM_H0.14, VRM_H0.15, VRM_H0.16, VRM_H1.11, VRM_H1.12, VRM_H1.13, VRM_H1.14, VRM_H1.15, VRM_H1.16; also elsewhere on the board
MGTAVCC: REG_FPGA.6; also elsewhere on the board
MGTAVTT: REG_FPGA.7; also elsewhere on the board
PMB_SCL: J_PSU0.13, J_PSU1.13, VRM_A0.17, VRM_A1.17, VRM_A2.17, VRM_A3.17, VRM_A4.17, VRM_A5.17, VRM_A6.17, VRM_A7.17, VRM_H0.17, VRM_H1.17; also elsewhere on the board
PMB_SDA: J_PSU0.14, J_PSU1.14, VRM_A0.18, VRM_A1.18, VRM_A2.18, VRM_A3.18, VRM_A4.18, VRM_A5.18, VRM_A6.18, VRM_A7.18, VRM_H0.18, VRM_H1.18; also elsewhere on the board
PSU_ON: J_PSU0.15, J_PSU1.15; also elsewhere on the board
VCCAUX_1V8: REG_FPGA.5; also elsewhere on the board
VCCINT_0V85: REG_FPGA.4; also elsewhere on the board
VCCO_1V2: REG_1V05.5; also elsewhere on the board
VCCO_1V8: REG_1V8.5; also elsewhere on the board
VDD1_1V8: REG_1V8.4; also elsewhere on the board
VDD2H_1V05: REG_1V05.4, REG_1V05.6, REG_1V05.7; also elsewhere on the board
VDD2L_0V9: REG_0V9.4, REG_0V9.6, REG_0V9.7; also elsewhere on the board
VDDQ_0V3: REG_0V3.4, REG_0V3.5, REG_0V3.6, REG_0V3.7; also elsewhere on the board
VDD_1V2: REG_DDR.4, REG_DDR.5, REG_DDR.7; also elsewhere on the board
VDD_3V3: REG_3V3.4, REG_3V3.5, REG_3V3.6, REG_3V3.7; also elsewhere on the board
VDD_CORE_A0: VRM_A0.5, VRM_A0.6, VRM_A0.7, VRM_A0.8, VRM_A0.9, VRM_A0.10; also elsewhere on the board
VDD_CORE_A1: VRM_A1.5, VRM_A1.6, VRM_A1.7, VRM_A1.8, VRM_A1.9, VRM_A1.10; also elsewhere on the board
VDD_CORE_A2: VRM_A2.5, VRM_A2.6, VRM_A2.7, VRM_A2.8, VRM_A2.9, VRM_A2.10; also elsewhere on the board
VDD_CORE_A3: VRM_A3.5, VRM_A3.6, VRM_A3.7, VRM_A3.8, VRM_A3.9, VRM_A3.10; also elsewhere on the board
VDD_CORE_A4: VRM_A4.5, VRM_A4.6, VRM_A4.7, VRM_A4.8, VRM_A4.9, VRM_A4.10; also elsewhere on the board
VDD_CORE_A5: VRM_A5.5, VRM_A5.6, VRM_A5.7, VRM_A5.8, VRM_A5.9, VRM_A5.10; also elsewhere on the board
VDD_CORE_A6: VRM_A6.5, VRM_A6.6, VRM_A6.7, VRM_A6.8, VRM_A6.9, VRM_A6.10; also elsewhere on the board
VDD_CORE_A7: VRM_A7.5, VRM_A7.6, VRM_A7.7, VRM_A7.8, VRM_A7.9, VRM_A7.10; also elsewhere on the board
VDD_CORE_H0: VRM_H0.5, VRM_H0.6, VRM_H0.7, VRM_H0.8, VRM_H0.9, VRM_H0.10; also elsewhere on the board
VDD_CORE_H1: VRM_H1.5, VRM_H1.6, VRM_H1.7, VRM_H1.8, VRM_H1.9, VRM_H1.10; also elsewhere on the board
VDD_IO_1V8: REG_1V8.6, REG_1V8.7; also elsewhere on the board
VDD_PLL_0V9: REG_0V9.5; also elsewhere on the board
VPP_2V5: REG_DDR.6; also elsewhere on the board
VRM_EN_A0: VRM_A0.19
VRM_EN_A1: VRM_A1.19
VRM_EN_A2: VRM_A2.19
VRM_EN_A3: VRM_A3.19
VRM_EN_A4: VRM_A4.19
VRM_EN_A5: VRM_A5.19
VRM_EN_A6: VRM_A6.19
VRM_EN_A7: VRM_A7.19
VRM_EN_H0: VRM_H0.19
VRM_EN_H1: VRM_H1.19

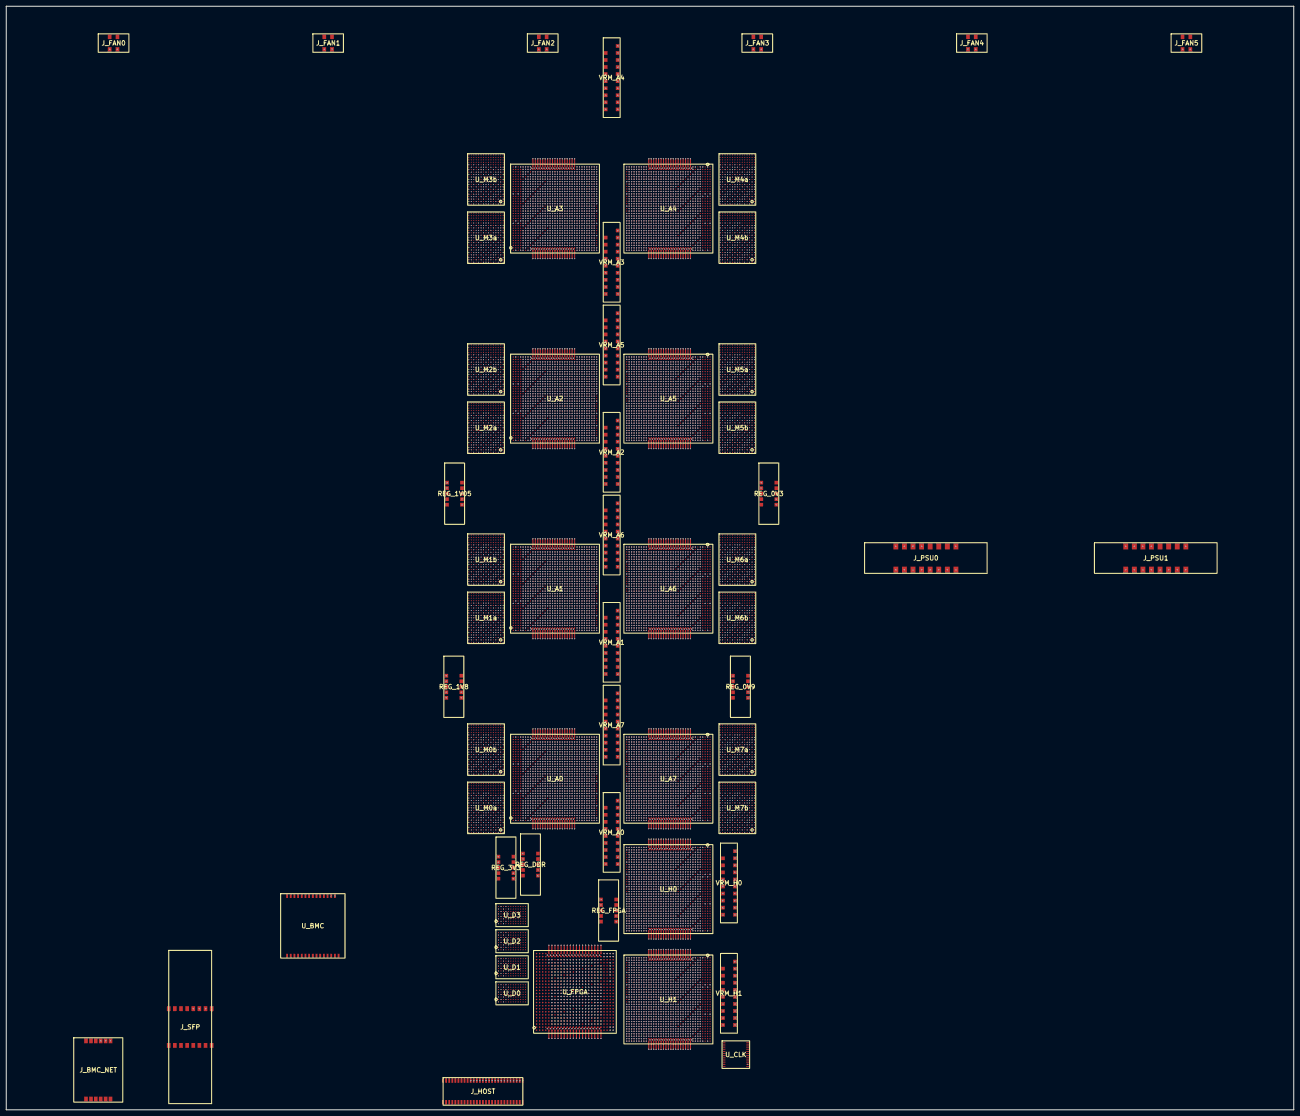
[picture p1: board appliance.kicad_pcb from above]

Board: 12 copper layers, 420.0 x 360.0 mm, 61 parts (0 on the bottom side), 1716 nets.

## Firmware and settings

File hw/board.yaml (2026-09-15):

# Appliance board: block-level schematic capture.
#
# This is the source of truth for the board netlist at the interface level.
# `python -m hw.board` checks it and renders hw/board.svg and hw/board.md.
# Every electrical number marked "placeholder" is a budget to validate, not a
# measured or vendor-confirmed value.

board:
  name: asic-llm-appliance-a0
  form_factor: 1U rack chassis, one 420 x 360 mm board, host-attached over a PCIe cable, front-to-back fans, redundant CRPS
  form_factor_key: 1u          # selects the enclosure model in hw/kicad_gen.py (1u or pcie_card)
  host_interface: PCIe Gen4 x8 over a SlimSAS 8i cable to a host adapter card (x4 electrically sufficient; see hw/README.md)
  power_input:
    # Two CRPS modules in a 1+1 redundant pair; one carries the whole load, so
    # the available input is one module's rating.  2000 W covers the 50K
    # tokens/s row of the power table with margin for the fans and the BMC.
    - {name: CRPS 12 V, 1+1 redundant pair (two 2000 W modules), watts: 2000}
  # The chassis follows from the energy model below: at 3 pJ per MAC the
  # board draws 0.5 to 1.6 kW of input across the throughput range, which is
  # a rack power supply, not a slot.  A 7 nm-class die at ~1 pJ/MAC would
  # bring the whole range under 600 W and make a PCIe card viable again.

# Energy model for the ASICs.  Dynamic power is throughput times energy per
# token; the per-MAC energy is the one number measured so far (0.39 pJ on
# ASAP7 at default activity, fabric/results/pnr_asap7_signoff.json), derated
# for real activity and projected to a 28 nm-class node.  The design point
# is the simulator's global-stage ceiling (sim/README.md).
power_model:
  mac_energy_pj: 3.0
  design_tokens_per_second: 14500
  memory_energy_pj_per_byte: 40.0
  memory_bytes_per_token_per_asic: 4200000   # index scan + selected KV at 128K, int8, 4:1
  report_tokens_per_second: [5000, 14500, 25000, 50000]

# ASIC package and ball map.  `python -m hw.pinout` derives them from the
# interface list, the power model and these rules: the core rail needs one
# ball per `amps_per_ball` at `rated_tokens_per_second`, ground matches it
# plus one return per `signals_per_ground` signal balls, signals must fit the
# outer `signal_rows` rows, and the smallest candidate that satisfies all of
# that wins.  The KiCad generator uses the same derived map.
package_selection:
  rated_tokens_per_second: 50000   # the 1U carries the 50K target; the package is rated for it
  amps_per_ball: 0.5
  signals_per_ground: 4
  signal_rows: 3
  edges: {link_in: W, link_out: E, lpddr: N, misc: S}
  candidates:
    - {name: FCBGA400_20x20_P1.0, cols: 20, rows: 20, pitch: 1.0, body: 23.0, ball: 0.45}
    - {name: FCBGA784_28x28_P0.8, cols: 28, rows: 28, pitch: 0.8, body: 23.0, ball: 0.40}
    - {name: FCBGA961_31x31_P1.0, cols: 31, rows: 31, pitch: 1.0, body: 33.0, ball: 0.45}
    - {name: FCBGA1225_35x35_P0.8, cols: 35, rows: 35, pitch: 0.8, body: 29.0, ball: 0.40}
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

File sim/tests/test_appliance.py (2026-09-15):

import json
import tempfile
import unittest
from dataclasses import replace
from pathlib import Path

from sim.appliance import ApplianceConfig, Simulation, WorkItem


SMALL = ApplianceConfig(
    clock_mhz=100,
    num_asics=2,
    layers_per_asic=4,
    resident_contexts=4,
    tokens_per_context=3,
    initial_context_tokens=16,
    warmup_tokens_per_context=0,
    recurrent_cycles=2,
    global_index_compute_cycles=3,
    global_topk_cycles=1,
    global_attention_cycles=1,
    global_output_cycles=1,
    fifo_depth=1,
    sampling_cycles=2,
    activation_bytes=8,
    packet_overhead_bytes=0,
    link_bytes_per_cycle=8,
    memory_bytes_per_cycle=1_000_000,
    compression_ratio=4,
    retrieval_block_size=2,
    top_blocks=1,
    local_window=2,
    index_dim=4,
    index_bits=4,
    head_dim=2,
    max_cycles=10_000,
)


class SimulationTest(unittest.TestCase):
    def test_completes_every_token_without_context_overlap(self) -> None:
        simulation = Simulation(SMALL)
        result = simulation.run()
        self.assertEqual(result.completed_tokens, 12)
        self.assertEqual([context.generated for context in simulation.contexts], [3] * 4)
        self.assertTrue(all(not context.in_flight for context in simulation.contexts))
        self.assertEqual([stage.counters.accepted for stage in simulation.stages], [12] * 8)

    def test_finite_fifos_create_backpressure_without_loss(self) -> None:
        config = replace(SMALL, recurrent_cycles=1, global_index_compute_cycles=12,
                         global_max_inflight=1, resident_contexts=8)
        result = Simulation(config).run()
        self.assertEqual(result.completed_tokens, 24)
        self.assertTrue(any(stalls > 0 for stalls in result.stage_output_stalls))
        self.assertTrue(all(depth <= config.fifo_depth for depth in result.fifo_high_watermarks))

    def test_longer_context_increases_full_scan_memory(self) -> None:
        short = Simulation(replace(SMALL, initial_context_tokens=16)).run()
        long = Simulation(replace(SMALL, initial_context_tokens=1024)).run()
        self.assertTrue(all(long_bytes > short_bytes for long_bytes, short_bytes
                            in zip(long.memory_bytes_per_asic, short.memory_bytes_per_asic)))

    def test_trace_is_chrome_compatible_json(self) -> None:
        simulation = Simulation(replace(SMALL, tokens_per_context=1, trace=True))
        simulation.run()
        with tempfile.TemporaryDirectory() as directory:
            path = Path(directory) / "trace.json"
            simulation.write_chrome_trace(path)
            events = json.loads(path.read_text(encoding="utf-8"))["traceEvents"]
        self.assertTrue(events)
        self.assertEqual(events[0]["ph"], "X")

    def test_warmup_tokens_are_excluded_from_metrics(self) -> None:
        config = replace(SMALL, warmup_tokens_per_context=2, tokens_per_context=1)
        simulation = Simulation(config)
        result = simulation.run()
        self.assertEqual(result.completed_tokens, config.resident_contexts)
        self.assertEqual([context.generated for context in simulation.contexts], [3] * 4)

    def test_global_phases_overlap_but_share_memory_interval(self) -> None:
        simulation = Simulation(SMALL)
        latency, interval, _ = simulation._timing(
            simulation.stages[3],
            WorkItem(0, 1024, 0, 0),
        )
        self.assertGreater(latency, interval)

    def test_head_asics_extend_the_ring_without_memory(self) -> None:
        config = replace(SMALL, num_head_asics=2, head_cycles=3, head_result_bytes=4)
        simulation = Simulation(config)
        self.assertEqual(len(simulation.stages), 10)
        self.assertEqual(len(simulation.links), 3)
        self.assertTrue(simulation.stages[8].is_head and simulation.stages[9].is_head)
        result = simulation.run()
        self.assertEqual(result.completed_tokens, 12)
        self.assertEqual([stage.counters.accepted for stage in simulation.stages], [12] * 10)
        self.assertEqual(len(result.memory_bytes_per_asic), config.num_asics)
        self.assertEqual(simulation.stages[8].counters.memory_bytes, 0)
        # The head hop carries the hidden vector plus the top-k partial result.
        self.assertGreater(result.link_utilization[2], result.link_utilization[0])
        self.assertGreater(result.mean_token_latency_cycles,
                           Simulation(SMALL).run().mean_token_latency_cycles)

    def test_rejects_invalid_configuration(self) -> None:
        with self.assertRaises(ValueError):
            Simulation(replace(SMALL, fifo_depth=0))
        with self.assertRaises(ValueError):
            Simulation(replace(SMALL, mac_energy_pj=-1.0))

    def test_energy_model_scales_with_mac_energy_and_throughput(self) -> None:
        config = replace(SMALL, mac_energy_pj=2.0, layer_macs_per_token=1e9, num_head_asics=2,
                         head_macs_per_token=5e8, static_power_w=10.0, memory_energy_pj_per_byte=1.0)
        result = Simulation(config).run()
        # 2 layer ASICs x 1e9 + 2 head ASICs x 5e8 = 3e9 MACs x 2 pJ = 6 mJ per token.
        self.assertAlmostEqual(result.compute_energy_per_token_mj, 6.0)
        self.assertAlmostEqual(result.compute_power_w, 6e-3 * result.aggregate_tokens_per_second)
        self.assertAlmostEqual(result.layer_asic_power_w, 2e-3 * result.aggregate_tokens_per_second)
        self.assertGreater(result.memory_power_w, 0.0)
        self.assertAlmostEqual(result.board_power_w, result.compute_power_w + result.memory_power_w + 10.0)
        doubled = Simulation(replace(config, mac_energy_pj=4.0)).run()
        self.assertAlmostEqual(doubled.compute_power_w, 2 * result.compute_power_w)
        self.assertAlmostEqual(doubled.memory_power_w, result.memory_power_w)

    def test_shipped_configurations_load_and_validate(self) -> None:
        configs = sorted((Path(__file__).resolve().parents[1] / "config").glob("*.json"))
        self.assertGreaterEqual(len(configs), 4)
        loaded = {path.stem: ApplianceConfig.from_json(path) for path in configs}
        for config in loaded.values():
            config.validate()
        hbm = [name for name in loaded if "hbm" in name]
        self.assertEqual(len(hbm), 2)
        for name in hbm:
            # HBM configurations: faster fabric, int4 KV at 16:1, far more bandwidth and contexts.
            self.assertLess(loaded[name].recurrent_cycles, loaded["baseline"].recurrent_cycles)
            self.assertGreater(loaded[name].memory_bytes_per_cycle, 10 * loaded["baseline"].memory_bytes_per_cycle)
            self.assertGreater(loaded[name].resident_contexts, loaded["baseline"].resident_contexts)
            self.assertLess(loaded[name].mac_energy_pj, loaded["baseline"].mac_energy_pj)

    def test_board_power_helper_matches_simulation(self) -> None:
        from sim.appliance import board_power_w, energy_per_token_mj
        config = replace(SMALL, mac_energy_pj=3.0, layer_macs_per_token=866e6, static_power_w=70.0)
        self.assertAlmostEqual(energy_per_token_mj(config), 2 * 866e6 * 3e-12 * 1e3)
        self.assertAlmostEqual(board_power_w(config, 1000.0), 2 * 866e6 * 3e-12 * 1000.0 + 70.0)


if __name__ == "__main__":
    unittest.main()

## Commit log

2026-09-14 Add board-level schematic capture and head-mode ASICs
    hw/: block-level board description (board.yaml) for revision A0 with
    eight layer ASICs, two head-mode ASICs, sixteen LPDDR5X x32 devices,
    one PCIe Gen4 FPGA with 4 GB DDR4, a clock generator, and an optional
    SFP+ cage. hw/board.py checks interface references, ring closure and
    order, per-ASIC memory attachment, and the power budget, then renders
    board.svg and board.md. Tests cover the checks and rendering.
    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
2026-09-14 Design the fixed-weight fabric tile
    fabric/: the tile is a via-programmed ROM of rows x 64 int4 coefficients
    read two rows per cycle, feeding 64 multiply-accumulate columns. Shared
    coefficient multiples per bank, ROM-selected add/sub per column, 24-bit
    accumulators, per-column SRAM requantization. Pure-wiring coefficients
    cannot be time-multiplexed, so the ROM is what lets arithmetic be shared;
    each chip is the base mask set plus one via mask.
    - tile.py: TileSpec, symmetric quantizer, compiler into zero-padded tiles
    with partial-sum reduction over row blocks, bit-exact tile_forward and
    requantize, via-pattern export, model-to-tile mapping for the Qwen3.5
    presets, and a placeholder den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
2026-09-14 Synthesize the fabric column datapath with open tooling
    fabric/synth.py runs yosys (native or yowasp-yosys) on fabric_columns
    against any liberty file and reports cells, flops, and area per column.
    Measured on SkyWater sky130 HD and IHP SG13G2 at 1, 2, and 4 rows per
    cycle; scaled by NAND2 area ratio, the results calibrate the density
    model's MAC entries (216 um2 per column plus 110 um2 per bank at 28 nm
    class), bringing the 9B layer die estimate from 229 to 205 mm2.
    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
2026-09-14 Calibrate the column datapath across four open libraries
    fabric/synth.py now accepts several liberty files, merges split
    libraries (ASAP7's SIMPLE/INVBUF/AO/OA/SEQ) into one block the way the
    OpenROAD flow does, and reports each result in NAND2 equivalents using
    the library's own smallest NAND2.
    Column datapath at two rows per cycle: sky130 HD 5221 um2, IHP SG13G2
    9349 um2, NanGate 45 1043 um2, ASAP7 74 um2; normalized, all four land
    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
2026-09-14 Time the fabric column on sky130 and ASAP7 and make it carry-chain free
    fabric/sta.py drives OpenSTA on a netlist written by fabric/synth.py
    (--target-ps for timing-driven mapping, --netlist to keep it), reports
    the clock path group's worst path in picoseconds, and strips the
    `wire signed` declarations OpenSTA rejects. synth.py gains a timing mode
    (ABC map -D plus buffering and stime, with a plain fallback where ABC
    aborts), liberty cell filtering for sky130's lpflow/probe cells, and a
    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
2026-09-14 Add an OpenROAD place-and-route driver for the fabric column
    fabric/pnr.py drives OpenROAD directly with the OpenROAD-flow-scripts
    platform files for sky130hd and asap7: floorplan, pin placement,
    timing-driven global placement, repair_design, CTS, hold/setup repair,
    global routing with estimated parasitics, and a final timing report
    (detailed routing optional). Results are parsed into picoseconds
    regardless of the library's time unit.
    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
2026-09-14 fabric: drop report_wire_length from the P&R flow, parse wirelength and overflow from the router log
    report_wire_length crashes the litex-hub OpenROAD build (its error path
    calls a misspelled utl:: command), which ended both runs right after
    global routing. The router already prints total wirelength and the final
    congestion table, so parse_results now reads those and PnrResult carries
    wirelength_um and overflow.
    Claude-Session: https://claude.ai/code/session_01VmmvkZe8Ctg3RAykNGsQBn
2026-09-14 fabric: OpenROAD place-and-route results on sky130 and ASAP7
    The column slice (256 rows, 16 columns, two rows per cycle) after global
    placement, CTS, hold repair and global routing: 241 MHz on sky130 HD and
    1.42 GHz on ASAP7, matching the pre-layout bracket of 0.6 to 1.2 GHz for a
    28 nm-class part. Sky130 area grows 34 percent in P&R (hold buffers and
    an 8-level clock tree); ASAP7 area is flat after resizing.
    pnr.py now accepts both 'wns X' and 'wns max X' report formats and the
    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
2026-09-14 fabric: power grid, detailed route, extraction and IR drop in the P&R flow
    The flow now inserts well taps and the platform power-grid strategy
    (pdngen) at floorplan, and with --detailed-route continues through
    detailed routing, fill cells, OpenRCX extraction, timing on the extracted
    parasitics, report_power and static IR-drop analysis on VDD and VSS.
    PnrResult carries the DRC count, total power and worst IR drop. The
    platform PDN scripts are filtered to the standard-cell grid because the
    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
2026-09-14 fabric: routability-driven placement with a density option
    The sky130 slice overflowed the local layers inside dense logic clusters
    (CSA trees and resolve stages) at the placer's default density whatever
    the die size, and the detailed router rejects nets whose guides are left
    incomplete. Placement is now routability-driven at a default target
    density of 0.5, adjustable with --place-density.
    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
2026-09-14 fabric: merge multi-port LEF pins for sky130, ASAP7 derating 0.25
    TritonRoute in the litex-hub build rejects nets on sky130 pins whose li1
    and met1 shapes are separate PORTs (xor2 B, dfrtp RESET_B, mux, fa) when
    the ports straddle a gcell boundary. The driver now rewrites those pins
    to one PORT in a copy of the cell LEF. ASAP7 routing derating follows the
    flow scripts' 0.25 instead of 0.5, and global routing gets 100 congestion
    iterations, which removes the marginal overflow that put guides on M9.
    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
2026-09-14 fabric: save the routed DEF before extraction, fix the OpenRCX call, IR-drop bump grid
    The litex-hub build takes the extraction rules as extract_parasitics
    -ext_model_file rather than set_extraction_rules_file, which cost one
    finished ASAP7 detailed route (0 DRC, 0 antenna violations) because the
    DEF was only written at the end. The flow now writes design_drt.def as
    soon as routing finishes, guards the SPEF read, and gives the IR-drop
    analysis a checkerboard of supply points (20 um on ASAP7, 100 um on
    sky130) instead of one point at die centre.
    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
2026-09-15 Energy model: measured energy per MAC drives simulator and board power
    The simulator config gains mac_energy_pj, MACs per token per layer and
    head ASIC, memory energy per byte and a static floor; results report
    energy per token, compute, memory and board power and per-ASIC dynamic
    power, and the sweep adds the same at each point's ceiling. The board
    description replaces the ASIC TDP placeholders with static_w plus
    macs_per_token and a power_model block; the power check now runs at a
    design throughput and board.md tabulates 5K to 50K tokens/s. At the
    projected 3 pJ per MAC the 14.5K tokens/s baseline is about 440 W of
    load, so the auxiliary connector becomes a 12V-2x6 and the core rails
    nee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
    [board.yaml, test_appliance.py]
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2026-09-15 hw: KiCad 7 project generated from board.yaml
    hw/kicad_gen.py writes a floorplan-level KiCad project directly in the
    S-expression formats: the full-length PCIe card outline with edge fingers
    and the 12V-2x6 connector, every part placed on generated footprints with
    a placeholder BGA ball map shared by all ten ASICs, all 1,744 nets, a
    twelve-layer stackup with ground, 12 V, memory-PHY and core-rail zones and
    via-in-pad on the rail balls, and the activation ring fully routed as
    escape vias plus orthogonal ribbons (bent hops split over two layers and
    compressed to 0.25 mm lanes). KiCad's DRC reports nothing but the
    unrouted memory, PCIe and management nets, which are left for interactive
    routin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
    [appliance.kicad_pcb, appliance.kicad_sch, asics.kicad_sch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]
2026-09-15 hw: derive the ASIC package and ball map from the power model
    hw/pinout.py turns the interface list, the power model and the
    package_selection rules in board.yaml into the ball count the core rail
    needs, the smallest candidate package that carries it, and a rule-based
    ball map (links on the west and east edges as two columns of 18 rows,
    both LPDDR channels on the north rows in byte lanes with ground returns,
    management on the south row, ground and core in a checkerboard), written
    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
    [appliance.kicad_pcb, appliance.kicad_sch, asic_ballmap.csv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]
2026-09-15 Retarget the board to a host-attached 1U chassis
    The energy model put the board at 0.5 to 1.6 kW of input across the
    throughput range, which is a rack supply, not a PCIe slot. The board is
    now one 420 x 360 mm board in a 1U: two CRPS modules in a 1+1 pair, a
    BMC with its own Ethernet, six front fans, and a SlimSAS 8i cable to the
    host's PCIe. With the room to carry it, the ASIC package is rated at the
    50K tokens/s target (177 A core), which selects the 1225-ball 29 mm
    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
    [appliance.kicad_pcb, appliance.kicad_sch, asic_ballmap.csv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]
